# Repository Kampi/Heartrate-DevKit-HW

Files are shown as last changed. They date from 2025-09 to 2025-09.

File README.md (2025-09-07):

# ZSWatch-Heartrate-DevKit



## 📑 Table of Contents

- [ZSWatch-Heartrate-DevKit](#zswatch-heartrate-devkit)
  - [📑 Table of Contents](#-table-of-contents)
  - [📖 About](#-about)
  - [📂 Directory Breakdown](#-directory-breakdown)
  - [Purchasing](#purchasing)
  - [Ressources](#ressources)
  - [👨‍💻 Maintainer](#-maintainer)

## 📖 About

The **ZSWatch-Heartrate-DevKit** project provides the hardware design and production files for a heartrate development board tailored to the ZSWatch ecosystem.
It is built with **KiCad** and integrates a full **CI/CD pipeline** using **KiBot**, ensuring reproducible outputs for documentation, manufacturing, and releases.

Key features:

- 🛠️ Open-source hardware design
- 📦 Automated generation of Gerber, BoM, and documentation via KiBot
- 🔄 Workflow stages (DRAFT → PRELIMINARY → CHECKED → RELEASED) for structured releases
- 📝 Clear documentation and changelog to track progress
- 🌍 Designed with collaboration and transparency in mind

Please check the [wiki](https://github.com/ZSWatch/ZSWatch/wiki) for more information about the project.

## 📂 Directory Breakdown

- **`.github`**: GitHub related files
- **`.gitignore`**: Ignored files list
- **`devkit`**: KiCad project for the devkit
- **`production`**: Manufacturing outputs (Gerbers, documentation, etc.)
- **`CHANGELOG.md`**: Version history
- **`LICENSE`**: Project license (GPL-3.0)
- **`README.md`**: Project overview

## Purchasing

TBD

## Ressources

- [KiBot Template](https://github.com/nguyen-v/KDT_Hierarchical_KiBot)

## 👨‍💻 Maintainer

- [Daniel Kampert](mailto:danielkameprt@kampis-elektroecke.de)

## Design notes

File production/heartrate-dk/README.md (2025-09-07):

<p align="center" width="100%">
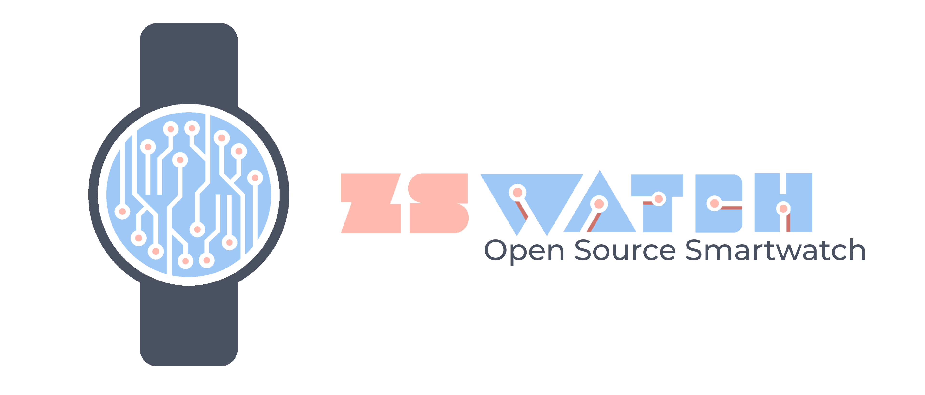
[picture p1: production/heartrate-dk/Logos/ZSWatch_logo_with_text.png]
  
</p>

<h1 align="center">Heartrate-DevKit-HW</h1>

<p align="center" width="100%">
  <a href="https://github.com/ZSWatch/Heartrate-DevKit-HW/actions/workflows/devkit.yaml">
    
  </a>
</p>

***

<p align="center">
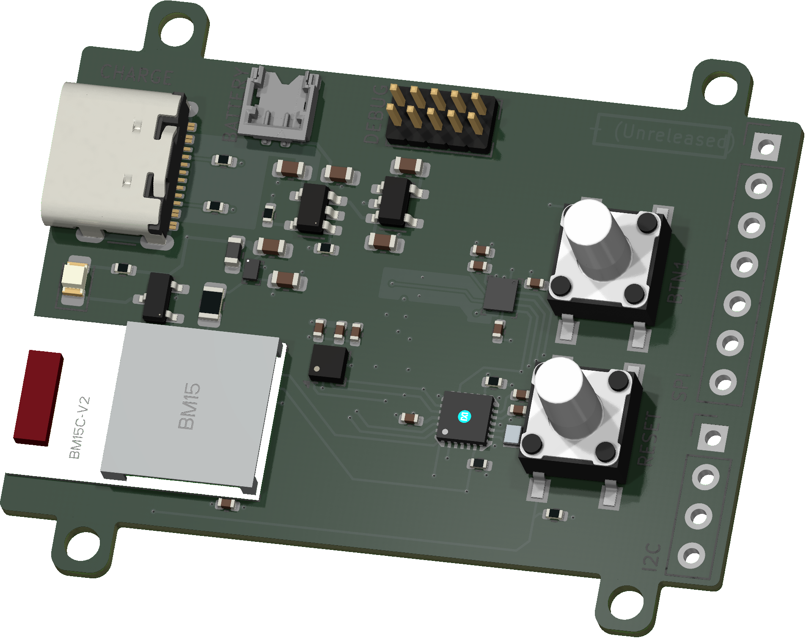
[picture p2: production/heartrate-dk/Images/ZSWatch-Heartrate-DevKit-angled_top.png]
3D Top Angled
  
&nbsp; &nbsp; &nbsp; &nbsp;
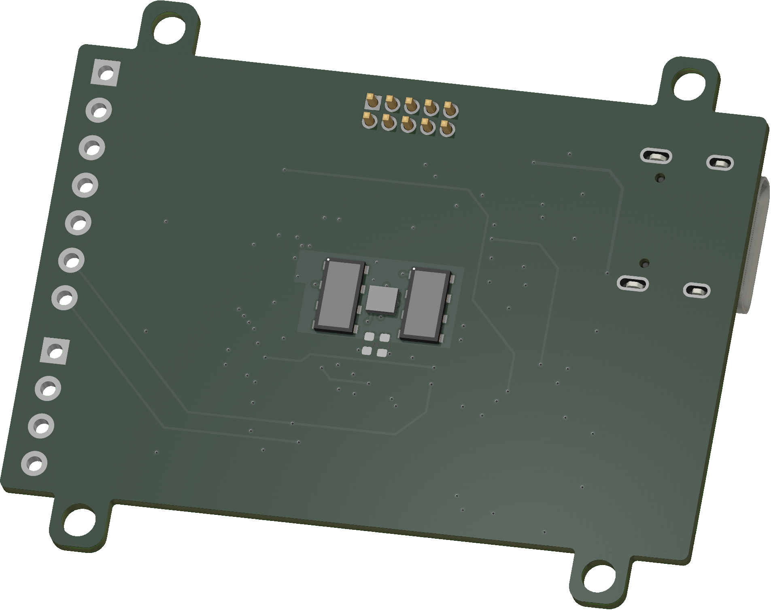
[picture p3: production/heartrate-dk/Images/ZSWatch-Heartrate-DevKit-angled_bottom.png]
3D Bottom Angled
  
</p>

***

## SPECIFICATIONS

| Parameter | Value |
| --- | --- |
| Dimensions | 45.0 × 36.9 mm |

***

## DIRECTORY STRUCTURE

    .
    ├─ Computations       # Misc calculations
    ├─ HTML               # HTML files for generated webpage
    ├─ Images             # Pictures and renders
    │
    ├─ kibot_resources    # External resources for KiBot
    │  ├─ colors          # Color theme for KiCad
    │  ├─ fonts           # Fonts used in the project
    │  ├─ scripts         # External scripts used with KiBot
    │  └─ templates       # Templates for KiBot generated reports
    │
    ├─ kibot_yaml         # KiBot YAML config files
    ├─ KiRI               # KiRI (PCB diff viewer) files
    │
    ├─ lib                # KiCad footprint and symbol libraries
    │  ├─ 3d_models       # Component 3D models
    │  ├─ lib_fp          # Footprint libraries
    │  └─ lib_sym         # Symbol libraries
    │
    ├─ Logos              # Logos
    │
    ├─ Manufacturing      # Assembly and fabrication documents
    │  ├─ Assembly        # Assembly documents (BoM, pos, notes)
    │  │
    │  └─ Fabrication     # Fabrication documents (ZIP, notes)
    │     ├─ Drill Tables # CSV drill tables
    │     └─ Gerbers      # Gerbers
    │
    ├─ Report             # Reports for ERC/DRC
    ├─ Schematic          # PDF of schematic
    ├─ Templates          # Title block templates
    ├─ Testing
    │  └─ Testpoints      # Testpoints tables
    │
    └─ Variants           # Outputs for assembly variants

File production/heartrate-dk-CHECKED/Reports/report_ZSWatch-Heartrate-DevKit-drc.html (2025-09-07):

Logo

| DRC report for ZSWatch-Heartrate-DevKit
| PCB: ZSWatch-Heartrate-DevKit Revision: + (Unreleased) Date: 2025-09-07T20:00:30+0000 KiCad Version: 9.0.1 | Errors: 1 Warnings: 15 Total: 16

Violations

Type | Description | Details
shorting_items | Items shorting two nets (nets and ) | @(219.2 mm, 138.1 mm): PCB text '+ (Unreleased)' on F.Cu @(215.1 mm, 137.2 mm): Rectangle [] on F.Cu
lib_footprint_issues | The current configuration does not include the footprint library 'Package_BGA_Kampi'. | @(195.65 mm, 149.625 mm): Footprint IC402
lib_footprint_mismatch | Footprint 'USB_C_Receptacle_GCT_USB4105-xx-A_16P_TopMnt_Horizontal' does not match copy in library 'Connector_USB'. | @(186.325 mm, 144.03 mm): Footprint X401
lib_footprint_issues | The current configuration does not include the footprint library 'Crystal_Kampi'. | @(213.5 mm, 158.275 mm): Footprint Y401
lib_footprint_issues | The current configuration does not include the footprint library 'Analog Devices'. | @(210.43 mm, 157.6 mm): Footprint IC404
lib_footprint_mismatch | Footprint 'SOT-23' does not match copy in library 'Package_TO_SOT_SMD'. | @(190.2625 mm, 152.125 mm): Footprint Q401
lib_footprint_issues | The current configuration does not include the footprint library 'Wuerth'. | @(217.85 mm, 157.525 mm): Footprint SW401
lib_footprint_mismatch | Footprint 'SOT-23-5' does not match copy in library 'Package_TO_SOT_SMD'. | @(203.7625 mm, 144.45 mm): Footprint IC401
lib_footprint_issues | The current configuration does not include the footprint library 'Fanstel'. | @(189.7 mm, 159.075 mm): Footprint M401
lib_footprint_issues | The current configuration does not include the footprint library 'Wuerth'. | @(217.85 mm, 147.3 mm): Footprint SW402
lib_footprint_mismatch | Footprint 'SOT-23-5' does not match copy in library 'Package_TO_SOT_SMD'. | @(198.8375 mm, 145.45 mm): Footprint IC403
lib_footprint_issues | The current configuration does not include the footprint library 'Molex'. | @(195.6 mm, 139.15 mm): Footprint X402
lib_footprint_issues | The current configuration does not include the footprint library 'Package_BGA_Kampi'. | @(211.2 mm, 149.475 mm): Footprint IC405
lib_footprint_issues | The current configuration does not include the footprint library 'Vishay'. | @(202.4 mm, 151.375 mm): Footprint D403
lib_footprint_issues | The current configuration does not include the footprint library 'Osram'. | @(205.2 mm, 151.375 mm): Footprint LED401
lib_footprint_issues | The current configuration does not include the footprint library 'Vishay'. | @(208.0 mm, 151.375 mm): Footprint D402

Generated by KiBot (https://github.com/INTI-CMNB/KiBot/) v1.8.4

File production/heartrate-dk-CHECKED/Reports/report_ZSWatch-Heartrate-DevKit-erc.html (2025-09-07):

Logo

| ERC report for ZSWatch-Heartrate-DevKit
| Schematic: ZSWatch-Heartrate-DevKit Revision: + (Unreleased) Date: 2025-09-07T20:00:28+0000 KiCad Version: 9.0.1 | Errors: 0 Warnings: 25 Total: 25

Sheet / (ZSWatch-Heartrate-DevKit.kicad_sch)

Type | Description | Details
footprint_link_issues | The current configuration does not include the footprint library 'Package_BGA_Kampi'. | @(0.508 mm, 0.9398 mm): Symbol IC402 [TPS61240-BGA]
lib_symbol_issues | The current configuration does not include the symbol library 'Texas Instruments' | @(0.508 mm, 0.9398 mm): Symbol IC402 [TPS61240-BGA]
lib_symbol_issues | The current configuration does not include the symbol library 'Microchip_Kampi' | @(0.4826 mm, 1.3081 mm): Symbol IC401 [MIC5365]
footprint_link_issues | The current configuration does not include the footprint library 'Molex'. | @(1.397 mm, 0.2159 mm): Symbol X402 [Conn_01x02]
footprint_link_issues | The current configuration does not include the footprint library 'Crystal_Kampi'. | @(1.9177 mm, 0.9017 mm): Symbol Y401 [Crystal]
footprint_link_issues | The current configuration does not include the footprint library 'Wuerth'. | @(0.2921 mm, 2.1082 mm): Symbol SW401 [SW_DPST]
footprint_link_issues | The current configuration does not include the footprint library 'Analog Devices'. | @(2.1463 mm, 0.8128 mm): Symbol IC404 [MAX32664-SPI-TQFN]
lib_symbol_issues | The current configuration does not include the symbol library 'Analog Devices' | @(2.1463 mm, 0.8128 mm): Symbol IC404 [MAX32664-SPI-TQFN]
footprint_link_issues | The current configuration does not include the footprint library 'Fanstel'. | @(0.8128 mm, 2.3495 mm): Symbol M401 [BM15C]
lib_symbol_issues | The current configuration does not include the symbol library 'Fanstel' | @(0.8128 mm, 2.3495 mm): Symbol M401 [BM15C]
footprint_link_issues | The current configuration does not include the footprint library 'Wuerth'. | @(1.3335 mm, 2.5019 mm): Symbol SW402 [SW_DPST]
footprint_link_issues | The current configuration does not include the footprint library 'Package_BGA_Kampi'. | @(3.1496 mm, 0.6731 mm): Symbol IC405 [MAX86141]
lib_symbol_issues | The current configuration does not include the symbol library 'Analog Devices' | @(3.1496 mm, 0.6731 mm): Symbol IC405 [MAX86141]
footprint_link_issues | The current configuration does not include the footprint library 'Vishay'. | @(3.4163 mm, 0.7366 mm): Symbol D402 [D_Photo]
footprint_link_issues | The current configuration does not include the footprint library 'Vishay'. | @(3.4163 mm, 0.7747 mm): Symbol D403 [D_Photo]
footprint_link_issues | The current configuration does not include the footprint library 'Osram'. | @(3.6957 mm, 0.6858 mm): Symbol LED401 [SFH7016]
lib_symbol_issues | The current configuration does not include the symbol library 'Osram' | @(3.6957 mm, 0.6858 mm): Symbol LED401 [SFH7016]
lib_symbol_issues | The current configuration does not include the symbol library 'ST' | @(3.2004 mm, 2.0828 mm): Symbol IC406 [LIS2DS12]
unresolved_variable | Unresolved text variable | @(0.8636 mm, 0.3175 mm): Text Box
unresolved_variable | Unresolved text variable | @(0.889 mm, 0.3556 mm): Text Box
unresolved_variable | Unresolved text variable | @(1.524 mm, 0.3175 mm): Text Box
unresolved_variable | Unresolved text variable | @(1.5494 mm, 0.3556 mm): Text Box
unresolved_variable | Unresolved text variable | @(2.1844 mm, 0.3175 mm): Text Box
unresolved_variable | Unresolved text variable | @(2.2098 mm, 0.3556 mm): Text Box

Sheet /Project Architecture/Main/ (Main.kicad_sch)

Type | Description | Details
multiple_net_names | Both +1V8 and VDD are attached to the same items; +1V8 will be used in the netlist | @(1.9177 mm, 2.4384 mm): Symbol #PWR0426 Pin 1 [Power input, Line] @(0.8128 mm, 1.9431 mm): Symbol M401 Hidden pin C8 [VDD, Power input, Line]

Generated by KiBot (https://github.com/INTI-CMNB/KiBot/) v1.8.4

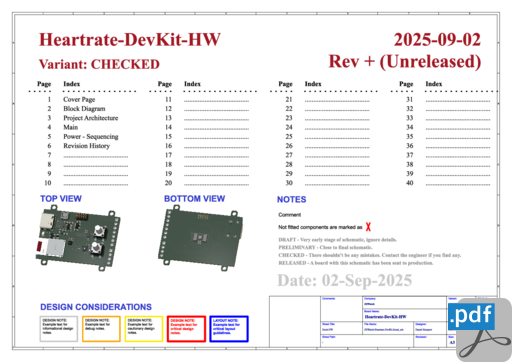
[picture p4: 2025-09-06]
production/heartrate-dk/HTML/images/cat_pdf_schematic_ZSWatch-Heartrate-DevKit-schematic.png

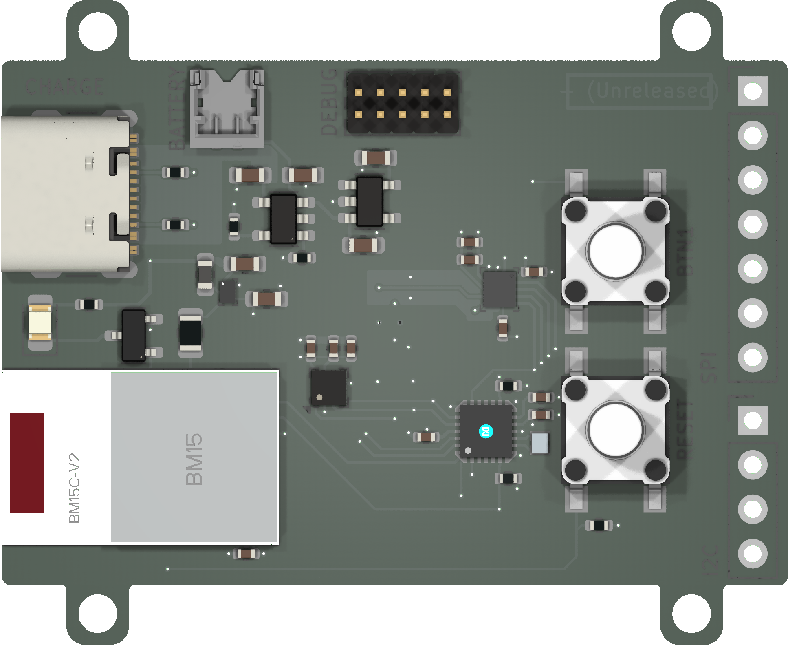
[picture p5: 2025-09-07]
production/heartrate-dk-CHECKED/Images/ZSWatch-Heartrate-DevKit-top.png

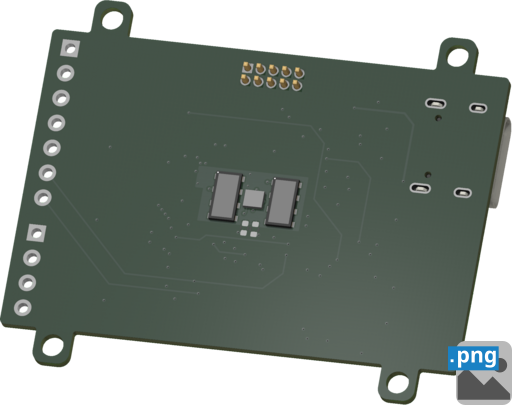
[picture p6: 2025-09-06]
production/heartrate-dk/HTML/images/cat_png_3d_viewer_angled_bottom_ZSWatch-Heartrate-DevKit-angled_bottom.png

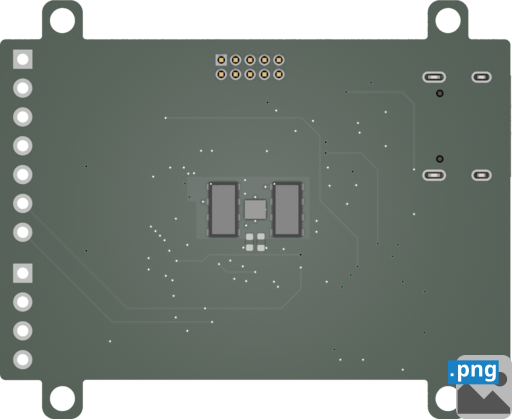
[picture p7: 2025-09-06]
production/heartrate-dk/HTML/images/cat_png_3d_viewer_bottom_ZSWatch-Heartrate-DevKit-bottom.png

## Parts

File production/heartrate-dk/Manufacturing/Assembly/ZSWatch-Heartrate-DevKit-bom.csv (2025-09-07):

Row | Quantity Per PCB | References | Value | Datasheet | Footprint | Description | manf | manf# | mouser#
1 | 4 | C406 C414 C415 C416 | 100n | https://www.yageogroup.com/content/datasheet/asset/file/KEM_C1002_X7R_SMD | C_0402_1005Metric | Unpolarized capacitor, small symbol | KEMET | C0402C104K4RAC7411 | 80-C0402C104K4R7411
2 | 2 | C402 C404 | 1u | https://www.mouser.de/datasheet/2/40/cx5r-2835979.pdf | C_0603_1608Metric | Unpolarized capacitor, small symbol | KYOCERA AVX | 06035C105MAT2A | 581-06035C105MAT2A
3 | 4 | C408 C409 C410 C413 | 1u | https://www.mouser.de/datasheet/2/40/cx5r-2835979.pdf | C_0402_1005Metric | Unpolarized capacitor, small symbol | KYOCERA AVX | 04023D105KAT2A | 581-04023D105KAT2A
4 | 1 | C401 | 2u2 | https://www.mouser.de/datasheet/2/40/cx5r-2835979.pdf | C_0603_1608Metric | Unpolarized capacitor, small symbol | KYOCERA AVX | 06033D225MAT2A | 581-06033D225MAT2A
5 | 3 | C403 C405 C407 | 4u7 | https://www.mouser.de/datasheet/2/396/mlcc02_e-1307760.pdf | C_0603_1608Metric | Unpolarized capacitor, small symbol | TAIYO YUDEN | LMK107BJ475KA-T | 963-LMK107BJ475KA-T
6 | 2 | C411 C412 | 10u | https://www.mouser.de/datasheet/2/396/mlcc02_e-1307760.pdf | C_0402_1005Metric | Unpolarized capacitor, small symbol | TAIYO YUDEN | AMK105CBJ106MV-F | 963-AMK105CBJ106MV-F
7 | 1 | C417 | 22u | https://www.mouser.de/datasheet/2/396/Taiyo_Yuden_2_8_2024_MEASJ063BB5225MF1A01_SS__1_-3395906.pdf | C_0402_1005Metric | Unpolarized capacitor, small symbol | TAIYO YUDEN | MEASP105CC6226MF1A01 | 963-MEASP105CC62261A
8 | 1 | D401 | STATUS | https://www.mouser.de/datasheet/2/678/hsmq_c170_t0000_ds100-2498198.pdf | LED_0805_2012Metric_Pad1.15x1.40mm_HandSolder | Light emitting diode | Broadcom / Avago | HSMQ-C170-T0000 | 630-HSMQ-C170-T0000
9 | 2 | D402 D403 | VEMD8082 | https://www.vishay.com/docs/80381/vemd8082.pdf | VEMD808x | Photodiode | Vishay Semiconductors | VEMD8082 | 78-VEMD8082
10 | 1 | IC406 | LIS2DS12 | https://www.st.com/resource/en/datasheet/lis2ds12.pdf | LGA-12_2x2mm_P0.5mm |  | STMicroelectronics | LIS2DS12 | 511-LIS2DS12
11 | 1 | IC404 | MAX32664 | https://www.analog.com/media/en/technical-documentation/data-sheets/MAX32664.pdf | MAX32664GTG |  | Analog Devices / Maxim Integrated | MAX32664GTGC+ | 700-MAX32664GTGC+
12 | 1 | IC405 | MAX86141 | https://www.analog.com/media/en/technical-documentation/data-sheets/max86140-max86141.pdf | THIN-WLP-20_2.228x1.967mm_P0.4mm |  | Analog Devices / Maxim Integrated | MAX86141ENP+T | 700-MAX86141ENP+T
13 | 1 | IC403 | MCP73832-2-OT | http://ww1.microchip.com/downloads/en/DeviceDoc/20001984g.pdf | SOT-23-5 | Single cell, Li-Ion/Li-Po charge management controller, 4.20V, Open-Drain Status Output, in SOT23-5 package | Microchip Technology / Atmel | MCP73832T-2ACI/OT | 579-MCP73832T-2ACI/OT
14 | 1 | IC401 | MIC5365-1.8 | https://ww1.microchip.com/downloads/en/DeviceDoc/mic5365.pdf | SOT-23-5 |  | Microchip Technology | MIC5365-1.8YD5-TR | 998- MIC5365-1.8YD5-TR
15 | 1 | IC402 | TPS61240 | https://www.ti.com/lit/ds/symlink/tps61240.pdf?ts=1729943439201 | DSBGA-6_0.886x1.288mm_2x3_P0.4mm |  | Texas Instruments | TPS61240YFFR | 595-TPS61240YFFR
16 | 1 | L401 | 1u | https://www.mouser.de/datasheet/2/3/ASMCI_0603-3318216.pdf | L_0603_1608Metric | Inductor | ABRACON | ASMCI-0603-1R0M-T | 815-ASMCI-0603-1R0MT
17 | 1 | LED401 | SFH7016 | https://look.ams-osram.com/m/1a73f8d425cfcc40/original/SFH-7016.pdf | SFH7016 |  | ams OSRAM | SFH 7016 | 720-SFH7016
18 | 1 | M401 | BM15C | https://www.mouser.de/datasheet/2/915/BM15C_2bProduct_2bSpecifications-3555318.pdf | BM15C | nRF54L module with chip antenna | Fanstel | BM15C | 308-BM15C
19 | 1 | Q401 | BSS138 | https://www.onsemi.com/pub/Collateral/BSS138-D.PDF | SOT-23 | 50V Vds, 0.22A Id, N-Channel MOSFET, SOT-23 | onsemi / Fairchild | BSS138 | 512-BSS138
20 | 1 | R403 | 0R | ~ | R_0805_2012Metric | Resistor, small symbol | Vishay | CRCW08050000Z0EBC | 71-CRCW08050000Z0EBC
21 | 1 | R401 | 220R | ~ | R_0402_1005Metric | Resistor, small symbol | Bourns | CR0402-JW-221GLF | 652-CR0402-JW-221GLF
22 | 1 | R409 | 4k7 | ~ | R_0402_1005Metric | Resistor, small symbol | YAGEO | RC0402FR-7D4K7L | 603-RC0402FR-7D4K7L
23 | 2 | R404 R405 | 5k1 | ~ | R_0402_1005Metric | Resistor, small symbol | Bourns | CR0402-FX-5101GLF | 652-CR0402-FX-5101GLF
24 | 4 | R402 R406 R407 R408 | 10k | ~ | R_0402_1005Metric | Resistor, small symbol | Bourns | CR0402-JW-103GLF | 652-CR0402-JW-103GLF
25 | 1 | SW402 | BTN1 | https://www.we-online.com/components/products/datasheet/430182095816.pdf | WS-TASV-6x6 | Double Pole Single Throw (DPST) Switch | Wurth Elektronik | 430182095816 | 710-430182095816
26 | 1 | SW401 | RESET | https://www.we-online.com/components/products/datasheet/430182095816.pdf | WS-TASV-6x6 | Double Pole Single Throw (DPST) Switch | Wurth Elektronik | 430182095816 | 710-430182095816
27 | 1 | X402 | BATTERY | https://www.molex.com/en-us/products/part-detail-pdf/781710002?display=pdf | 78171-0002 | Generic connector, single row, 01x02, script generated (kicad-library-utils/schlib/autogen/connector/) | Molex | 78171-0002 | 538-78171-0002
28 | 1 | X401 | CHARGE | https://www.usb.org/sites/default/files/documents/usb_type-c.zip | USB_C_Receptacle_GCT_USB4105-xx-A_16P_TopMnt_Horizontal | USB 2.0-only 14P Type-C Receptacle connector | GCT | USB4105-GF-A-120 | 640-USB4105-GF-A-120
29 | 1 | X403 | DEBUG | http://infocenter.arm.com/help/topic/com.arm.doc.ddi0314h/DDI0314H_coresight_components_trm.pdf | PinHeader_2x05_P1.27mm_Vertical | Cortex Debug Connector, standard ARM Cortex-M SWD and JTAG interface | Wurth Elektronik | 623310235521 | 710-623310235521
30 | 1 | Y401 | 32kHz | https://www.mouser.de/datasheet/2/122/ECX_1210-2400578.pdf | ECS_ECX-1210 | Two pin crystal | ECS | ECS-.327-6-1210-TR | 520-.327-6-1210-TR

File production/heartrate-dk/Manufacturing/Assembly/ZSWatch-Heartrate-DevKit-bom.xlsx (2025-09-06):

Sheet: BoM
Bill of Materials
Schematic: | ZSWatch-Heartrate-DevKit | Component Groups: | 33
Variant: | CHECKED | Component Count: | 48 (45 SMD/ 3 THT)
Revision: |  | Fitted Components: | 45 (44 SMD/ 1 THT)
Date: | 2025-07-13 | Number of PCBs: | 1
KiCad Version: | 9.0.1+1 | Total Components: | 45
Row | Quantity Per PCB | References | Value | Datasheet | Footprint | Description | manf | manf#
1 | 4 | C406 C414 C415 C416 | 100n | https://www.yageogroup.com/content/datasheet/asset/file/KEM_C1002_X7R_SMD | C_0402_1005Metric | Unpolarized capacitor, small symbol | KEMET | C0402C104K4RAC7411
2 | 2 | C402 C404 | 1u | https://www.mouser.de/datasheet/2/40/cx5r-2835979.pdf | C_0603_1608Metric | Unpolarized capacitor, small symbol | KYOCERA AVX | 06035C105MAT2A
3 | 4 | C408 C409 C410 C413 | 1u | https://www.mouser.de/datasheet/2/40/cx5r-2835979.pdf | C_0402_1005Metric | Unpolarized capacitor, small symbol | KYOCERA AVX | 04023D105KAT2A
4 | 1 | C401 | 2u2 | https://www.mouser.de/datasheet/2/40/cx5r-2835979.pdf | C_0603_1608Metric | Unpolarized capacitor, small symbol | KYOCERA AVX | 06033D225MAT2A
5 | 3 | C403 C405 C407 | 4u7 | https://www.mouser.de/datasheet/2/396/mlcc02_e-1307760.pdf | C_0603_1608Metric | Unpolarized capacitor, small symbol | TAIYO YUDEN | LMK107BJ475KA-T
6 | 2 | C411 C412 | 10u | https://www.mouser.de/datasheet/2/396/mlcc02_e-1307760.pdf | C_0402_1005Metric | Unpolarized capacitor, small symbol | TAIYO YUDEN | AMK105CBJ106MV-F
7 | 1 | C417 | 22u | https://www.mouser.de/datasheet/2/396/Taiyo_Yuden_2_8_2024_MEASJ063BB5225MF1A01_SS__1_-3395906.pdf | C_0402_1005Metric | Unpolarized capacitor, small symbol | TAIYO YUDEN | MEASP105CC6226MF1A01
8 | 1 | D401 | STATUS | https://www.mouser.de/datasheet/2/678/hsmq_c170_t0000_ds100-2498198.pdf | LED_0805_2012Metric_Pad1.15x1.40mm_HandSolder | Light emitting diode | Broadcom / Avago | HSMQ-C170-T0000
9 | 2 | D402 D403 | VEMD8082 | https://www.vishay.com/docs/80381/vemd8082.pdf | VEMD808x | Photodiode | Vishay Semiconductors | VEMD8082
10 | 1 | IC406 | LIS2DS12 | https://www.st.com/resource/en/datasheet/lis2ds12.pdf | LGA-12_2x2mm_P0.5mm |  | STMicroelectronics | LIS2DS12
11 | 1 | IC404 | MAX32664 | https://www.analog.com/media/en/technical-documentation/data-sheets/MAX32664.pdf | MAX32664GTG |  | Analog Devices / Maxim Integrated | MAX32664GTGC+
12 | 1 | IC405 | MAX86141 | https://www.analog.com/media/en/technical-documentation/data-sheets/max86140-max86141.pdf | THIN-WLP-20_2.228x1.967mm_P0.4mm |  | Analog Devices / Maxim Integrated | MAX86141ENP+T
13 | 1 | IC403 | MCP73832-2-OT | http://ww1.microchip.com/downloads/en/DeviceDoc/20001984g.pdf | SOT-23-5 | Single cell, Li-Ion/Li-Po charge management controller, 4.20V, Open-Drain Status Output, in SOT23-5 package | Microchip Technology / Atmel | MCP73832T-2ACI/OT
14 | 1 | IC401 | MIC5365-1.8 | https://ww1.microchip.com/downloads/en/DeviceDoc/mic5365.pdf | SOT-23-5 |  | Microchip Technology | MIC5365-1.8YD5-TR
15 | 1 | IC402 | TPS61240 | https://www.ti.com/lit/ds/symlink/tps61240.pdf?ts=1729943439201 | DSBGA-6_0.886x1.288mm_2x3_P0.4mm |  | Texas Instruments | TPS61240YFFR
16 | 1 | L401 | 1u | https://www.mouser.de/datasheet/2/3/ASMCI_0603-3318216.pdf | L_0603_1608Metric | Inductor | ABRACON | ASMCI-0603-1R0M-T
17 | 1 | LED401 | SFH7016 | https://look.ams-osram.com/m/1a73f8d425cfcc40/original/SFH-7016.pdf | SFH7016 |  | ams OSRAM | SFH 7016
18 | 1 | M401 | BM15C | https://www.mouser.de/datasheet/2/915/BM15C_2bProduct_2bSpecifications-3555318.pdf | BM15C | nRF54L module with chip antenna | Fanstel | BM15C
19 | 1 | Q401 | BSS138 | https://www.onsemi.com/pub/Collateral/BSS138-D.PDF | SOT-23 | 50V Vds, 0.22A Id, N-Channel MOSFET, SOT-23 | onsemi / Fairchild | BSS138
20 | 1 | R403 | 0R | ~ | R_0805_2012Metric | Resistor, small symbol | Vishay | CRCW08050000Z0EBC
21 | 1 | R401 | 220R | ~ | R_0402_1005Metric | Resistor, small symbol | Bourns | CR0402-JW-221GLF
22 | 1 | R409 | 4k7 | ~ | R_0402_1005Metric | Resistor, small symbol | YAGEO | RC0402FR-7D4K7L
23 | 2 | R404 R405 | 5k1 | ~ | R_0402_1005Metric | Resistor, small symbol | Bourns | CR0402-FX-5101GLF
24 | 4 | R402 R406 R407 R408 | 10k | ~ | R_0402_1005Metric | Resistor, small symbol | Bourns | CR0402-JW-103GLF
25 | 1 | SW402 | BTN1 | https://www.we-online.com/components/products/datasheet/430182095816.pdf | WS-TASV-6x6 | Double Pole Single Throw (DPST) Switch | Wurth Elektronik | 430182095816
26 | 1 | SW401 | RESET | https://www.we-online.com/components/products/datasheet/430182095816.pdf | WS-TASV-6x6 | Double Pole Single Throw (DPST) Switch | Wurth Elektronik | 430182095816
27 | 1 | X402 | BATTERY | https://www.molex.com/en-us/products/part-detail-pdf/781710002?display=pdf | 78171-0002 | Generic connector, single row, 01x02, script generated (kicad-library-utils/schlib/autogen/connector/) | Molex | 78171-0002
28 | 1 | X401 | CHARGE | https://www.usb.org/sites/default/files/documents/usb_type-c.zip | USB_C_Receptacle_GCT_USB4105-xx-A_16P_TopMnt_Horizontal | USB 2.0-only 14P Type-C Receptacle connector | GCT | USB4105-GF-A-120
29 | 1 | X403 | DEBUG | http://infocenter.arm.com/help/topic/com.arm.doc.ddi0314h/DDI0314H_coresight_components_trm.pdf | PinHeader_2x05_P1.27mm_Vertical | Cortex Debug Connector, standard ARM Cortex-M SWD and JTAG interface | Wurth Elektronik | 623310235521
30 | 1 | Y401 | 32kHz | https://www.mouser.de/datasheet/2/122/ECX_1210-2400578.pdf | ECS_ECX-1210 | Two pin crystal | ECS | ECS-.327-6-1210-TR

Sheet: DNF
Bill of Materials
Schematic: | ZSWatch-Heartrate-DevKit | Component Groups: | 33
Variant: | CHECKED | Component Count: | 48 (45 SMD/ 3 THT)
Revision: |  | Fitted Components: | 45 (44 SMD/ 1 THT)
Date: | 2025-07-13 | Number of PCBs: | 1
KiCad Version: | 9.0.1+1 | Total Components: | 45
Row | Quantity Per PCB | References | Value | Datasheet | Footprint | Description | manf | manf#
1 | 1 | J401 | I2C | ~ | PinHeader_1x04_P2.54mm_Vertical | Generic connector, single row, 01x04, script generated (kicad-library-utils/schlib/autogen/connector/)
2 | 1 | J402 | SPI | ~ | PinHeader_1x07_P2.54mm_Vertical | Generic connector, single row, 01x07, script generated (kicad-library-utils/schlib/autogen/connector/)
3 | 1 | R410 | ~ | ~ | R_0402_1005Metric | Resistor, small symbol

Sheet: Costs
Bill of Materials
Schematic: | ZSWatch-Heartrate-DevKit |  |  |  |  | Board Qty: | 1
Variant: | CHECKED |  |  |  |  | Unit Cost: | $0.00
Revision: |  |  |  |  |  | Total Cost: | $0.00 |  |  |  |  | $0.00 | 0 of 30 parts found
Date: | 2025-07-13
KiCad Version: | 9.0.1+1
Global Part Info |  |  |  |  |  |  |  | Mouser
References | Value | Footprint | Manf | Manf# | Build Quantity | Unit$ | Ext$ | Avail | Purch | Unit$ | MOQ | Ext$ | Cat#
C406 C414 C415 C416 | 100n | C_0402_1005Metric | KEMET | C0402C104K4RAC7411 (https://www.yageogroup.com/content/datasheet/asset/file/KEM_C1002_X7R_SMD) | 4
C402 C404 | 1u | C_0603_1608Metric | KYOCERA AVX | 06035C105MAT2A (https://www.mouser.de/datasheet/2/40/cx5r-2835979.pdf) | 2
C408 C409 C410 C413 | 1u | C_0402_1005Metric | KYOCERA AVX | 04023D105KAT2A (https://www.mouser.de/datasheet/2/40/cx5r-2835979.pdf) | 4
C401 | 2u2 | C_0603_1608Metric | KYOCERA AVX | 06033D225MAT2A (https://www.mouser.de/datasheet/2/40/cx5r-2835979.pdf) | 1
C403 C405 C407 | 4u7 | C_0603_1608Metric | TAIYO YUDEN | LMK107BJ475KA-T (https://www.mouser.de/datasheet/2/396/mlcc02_e-1307760.pdf) | 3
C411 C412 | 10u | C_0402_1005Metric | TAIYO YUDEN | AMK105CBJ106MV-F (https://www.mouser.de/datasheet/2/396/mlcc02_e-1307760.pdf) | 2
C417 | 22u | C_0402_1005Metric | TAIYO YUDEN | MEASP105CC6226MF1A01 (https://www.mouser.de/datasheet/2/396/Taiyo_Yuden_2_8_2024_MEASJ063BB5225MF1A01_SS__1_-3395906.pdf) | 1
D401 | STATUS | LED_0805_2012Metric_Pad1.15x1.40mm_HandSolder | Broadcom / Avago | HSMQ-C170-T0000 (https://www.mouser.de/datasheet/2/678/hsmq_c170_t0000_ds100-2498198.pdf) | 1
D402 D403 | VEMD8082 | VEMD808x | Vishay Semiconductors | VEMD8082 (https://www.vishay.com/docs/80381/vemd8082.pdf) | 2
IC406 | LIS2DS12 | LGA-12_2x2mm_P0.5mm | STMicroelectronics | LIS2DS12 (https://www.st.com/resource/en/datasheet/lis2ds12.pdf) | 1
IC404 | MAX32664 | MAX32664GTG | Analog Devices / Maxim Integrated | MAX32664GTGC+ (https://www.analog.com/media/en/technical-documentation/data-sheets/MAX32664.pdf) | 1
IC405 | MAX86141 | THIN-WLP-20_2.228x1.967mm_P0.4mm | Analog Devices / Maxim Integrated | MAX86141ENP+T (https://www.analog.com/media/en/technical-documentation/data-sheets/max86140-max86141.pdf) | 1
IC403 | MCP73832-2-OT | SOT-23-5 | Microchip Technology / Atmel | MCP73832T-2ACI/OT (http://ww1.microchip.com/downloads/en/DeviceDoc/20001984g.pdf) | 1
IC401 | MIC5365-1.8 | SOT-23-5 | Microchip Technology | MIC5365-1.8YD5-TR (https://ww1.microchip.com/downloads/en/DeviceDoc/mic5365.pdf) | 1
IC402 | TPS61240 | DSBGA-6_0.886x1.288mm_2x3_P0.4mm | Texas Instruments | TPS61240YFFR (https://www.ti.com/lit/ds/symlink/tps61240.pdf?ts=1729943439201) | 1
L401 | 1u | L_0603_1608Metric | ABRACON | ASMCI-0603-1R0M-T (https://www.mouser.de/datasheet/2/3/ASMCI_0603-3318216.pdf) | 1
LED401 | SFH7016 | SFH7016 | ams OSRAM | SFH 7016 (https://look.ams-osram.com/m/1a73f8d425cfcc40/original/SFH-7016.pdf) | 1
M401 | BM15C | BM15C | Fanstel | BM15C (https://www.mouser.de/datasheet/2/915/BM15C_2bProduct_2bSpecifications-3555318.pdf) | 1
Q401 | BSS138 | SOT-23 | onsemi / Fairchild | BSS138 (https://www.onsemi.com/pub/Collateral/BSS138-D.PDF) | 1
R403 | 0R | R_0805_2012Metric | Vishay | CRCW08050000Z0EBC | 1
R401 | 220R | R_0402_1005Metric | Bourns | CR0402-JW-221GLF | 1
R409 | 4k7 | R_0402_1005Metric | YAGEO | RC0402FR-7D4K7L | 1
R404 R405 | 5k1 | R_0402_1005Metric | Bourns | CR0402-FX-5101GLF | 2
R402 R406 R407 R408 | 10k | R_0402_1005Metric | Bourns | CR0402-JW-103GLF | 4
SW402 | BTN1 | WS-TASV-6x6 | Wurth Elektronik | 430182095816 (https://www.we-online.com/components/products/datasheet/430182095816.pdf) | 1
SW401 | RESET | WS-TASV-6x6 | Wurth Elektronik | 430182095816 (https://www.we-online.com/components/products/datasheet/430182095816.pdf) | 1
X402 | BATTERY | 78171-0002 | Molex | 78171-0002 (https://www.molex.com/en-us/products/part-detail-pdf/781710002?display=pdf) | 1
X401 | CHARGE | USB_C_Receptacle_GCT_USB4105-xx-A_16P_TopMnt_Horizontal | GCT | USB4105-GF-A-120 (https://www.usb.org/sites/default/files/documents/usb_type-c.zip) | 1
X403 | DEBUG | PinHeader_2x05_P1.27mm_Vertical | Wurth Elektronik | 623310235521 (http://infocenter.arm.com/help/topic/com.arm.doc.ddi0314h/DDI0314H_coresight_components_trm.pdf) | 1
Y401 | 32kHz | ECS_ECX-1210 | ECS | ECS-.327-6-1210-TR (https://www.mouser.de/datasheet/2/122/ECX_1210-2400578.pdf) | 1
 |  |  |  |  |  | Total Purchase: | $0.00 | Buy here (https://mouser.com/bom/) |  |  |  | $0.00
Created: | 2025-09-06 09:58:40 |  |  |  |  | Purchase description:
KiCost® v1.1.20 + KiBot v1.8.4

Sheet: Costs (DNF)
Bill of Materials
Schematic: | ZSWatch-Heartrate-DevKit |  |  |  | Board Qty: | 1
Variant: | CHECKED |  |  |  | Unit Cost: | $0.00
Revision: |  |  |  |  | Total Cost: | $0.00 |  |  |  |  | $0.00 | 0 of 3 parts found
Date: | 2025-07-13
KiCad Version: | 9.0.1+1
Global Part Info |  |  |  |  |  |  | Mouser
References | Value | Footprint | Manf# | Build Quantity | Unit$ | Ext$ | Avail | Purch | Unit$ | MOQ | Ext$ | Cat#
J401 | I2C | PinHeader_1x04_P2.54mm_Vertical |  | 1
J402 | SPI | PinHeader_1x07_P2.54mm_Vertical |  | 1
R410 | ~ | R_0402_1005Metric |  | 1
 |  |  |  |  | Total Purchase: | $0.00 | Buy here (https://mouser.com/bom/) |  |  |  | $0.00
Created: | 2025-09-06 09:58:40 |  |  |  | Purchase description:
KiCost® v1.1.20 + KiBot v1.8.4

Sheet: Colors
Columns colors
KiCad Fields (default)
Generated Fields
User Fields
Empty Fields
Costs sheet colors
Best price
No manufacturer or distributor code
Not available
Purchase quantity is more than what is available
Minimum order quantity not respected
Total available part quantity is less than needed
Total purchased part quantity is less than needed
This part is obsolete
This part is listed but is not normally stocked

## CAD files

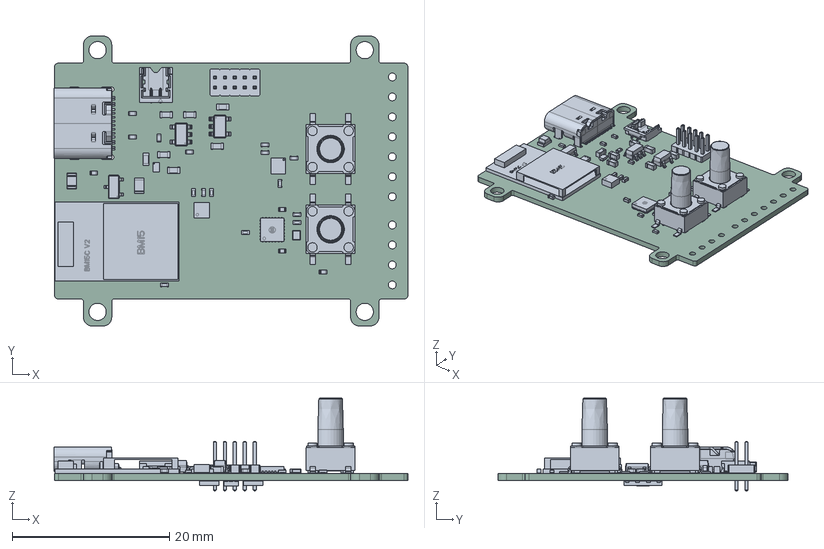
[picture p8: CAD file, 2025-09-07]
production/heartrate-dk-CHECKED/3D/ZSWatch-Heartrate-DevKit.step
45.0 x 36.9 x 11.8 mm
C_0603_1608Metric x 6
C_0402_1005Metric x 11
R_0805_2012Metric
TPS610994YFFR
USB_C_Receptacle_GCT_USB4105-xx-A_16P_TopMnt_Horizontal
R_0402_1005Metric x 8
PinHeader_2x05_P1.27mm_Vertical
LED_0805_2012Metric
solidBody
solidTop1
solidLead
MAXIM_90-100089
SOT-23
LGA-12_2x2mm_P0.5mm
SOT-23-5 x 2
BM15
BM15C-V2
L_0603_1608Metric
VEMD8080 x 2
SFH7016
kibot_rgkx_kim_PCB

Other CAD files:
production/heartrate-dk-RELEASED/3D/ZSWatch-Heartrate-DevKit.step
production/heartrate-dk/3D/ZSWatch-Heartrate-DevKit.step

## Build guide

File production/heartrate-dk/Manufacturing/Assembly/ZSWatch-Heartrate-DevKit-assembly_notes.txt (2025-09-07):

ASSEMBLY NOTES (UNLESS OTHERWISE SPECIFIED)

1)	DO NOT POPULATE PARTS ARE MARKED WITH A RED CROSS.

2)	DO NOT POPULATE PARTS ARE NOT PRESENT IN THE BOM.

3)	IF CONFLICTING INFORMATION IS FOUND BETWEEN THE ASSEMBLY
	FILE AND BOM, BOM SHOULD BE USED AS THE MAIN SOURCE.

4)	CONFORMAL COATING IS NOT REQUIRED.

5)	DOT IDENTIFIES PIN #1 LOCATION AND DEVICE ORIENTATION
	WHEN VIEWED FROM THE TOP.

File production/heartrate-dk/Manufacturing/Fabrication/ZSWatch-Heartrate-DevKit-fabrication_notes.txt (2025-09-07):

FABRICATION NOTES (UNLESS OTHERWISE SPECIFIED)

1)	FABRICATE PER IPC-6012A CLASS 2.

2)	OUTLINE DEFINED IN SEPARATE GERBER FILE WITH
	"Edge_Cuts.GBR" SUFFIX.

	DIMENSIONS OF CIRCUMSIZED RECTANGLE SHOWN ON THIS
	DRAWING FOR REFERENCE ONLY.

3)	SEE SEPARATE DRILL FILES WITH ".DRL" SUFFIX 
	FOR HOLE LOCATIONS.

	SELECTED HOLE LOCATIONS SHOWN ON THIS DRAWING 
	FOR REFERENCE ONLY.

4)	SURFACE FINISH: HAL SNPB

5)	SOLDERMASK ON BOTH SIDES OF THE BOARD SHALL 
	BE LPI, COLOR GREEN.

6)	SILK SCREEN LEGEND TO BE APPLIED PER LAYER 
	STACKUP USING BLACK NON-CONDUCTIVE EPOXY INK.

7)	ALL VIAS ARE TENTED ON BOTH SIDES UNLESS 
	SOLDERMASK OPENED IN GERBER.

8)	VENDOR SHOULD FOLLOW ROHS COMPLIANT PROCESS 
	AND Pb FREE FOR MANUFACTURING

9)	PCB MATERIAL REQUIREMENTS:

	A.	FLAMMABILITY RATING MUST MEET OR EXCEED 
		UL94V-0 REQUIREMENTS.
	B.	Tg 150 C OR EQUIVALENT.
	C.	EQUIVALENT MATERIAL SHALL BE RoHS COMPLIANT, 
		HALOGEN FREE AND APPROVED BY ZSWATCH.

10)	DESIGN GEOMETRY MINIMUM FEATURE SIZES:

	BOARD SIZE				45.000 × 36.900 mm
	BOARD THICKNESS		0.982 mm
	TRACE WIDTH			0.150 mm
	TRACE TO TRACE		0.100 mm
	MIN. HOLE (PTH)			0.150 mm
	MIN. HOLE (NPTH)		0.650 mm
	ANNULAR RING			0.100 mm
	COPPER TO HOLE		0.100 mm
	COPPER TO EDGE		0.100 mm
	HOLE TO HOLE			0.100 mm

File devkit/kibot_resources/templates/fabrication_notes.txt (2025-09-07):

FABRICATION NOTES (UNLESS OTHERWISE SPECIFIED)

1)	FABRICATE PER IPC-6012A CLASS 2.

2)	OUTLINE DEFINED IN SEPARATE GERBER FILE WITH
	"Edge_Cuts.GBR" SUFFIX.

	DIMENSIONS OF CIRCUMSIZED RECTANGLE SHOWN ON THIS
	DRAWING FOR REFERENCE ONLY.

3)	SEE SEPARATE DRILL FILES WITH ".DRL" SUFFIX 
	FOR HOLE LOCATIONS.

	SELECTED HOLE LOCATIONS SHOWN ON THIS DRAWING 
	FOR REFERENCE ONLY.

4)	SURFACE FINISH: ${pcb_finish_cap}

5)	SOLDERMASK ON BOTH SIDES OF THE BOARD SHALL 
	BE LPI, COLOR ${solder_mask_color_text_cap}.

6)	SILK SCREEN LEGEND TO BE APPLIED PER LAYER 
	STACKUP USING ${silk_screen_color_text_cap} NON-CONDUCTIVE EPOXY INK.

7)	ALL VIAS ARE TENTED ON BOTH SIDES UNLESS 
	SOLDERMASK OPENED IN GERBER.

8)	VENDOR SHOULD FOLLOW ROHS COMPLIANT PROCESS 
	AND Pb FREE FOR MANUFACTURING

9)	PCB MATERIAL REQUIREMENTS:

	A.	FLAMMABILITY RATING MUST MEET OR EXCEED 
		UL94V-0 REQUIREMENTS.
	B.	Tg 150 C OR EQUIVALENT.
	C.	EQUIVALENT MATERIAL SHALL BE RoHS COMPLIANT, 
		HALOGEN FREE AND APPROVED BY ${COMPANY_cap}.

10)	DESIGN GEOMETRY MINIMUM FEATURE SIZES:

	BOARD SIZE				${bb_w_mm} × ${bb_h_mm} mm
	BOARD THICKNESS		${thickness_mm} mm
	TRACE WIDTH			${track_mm} mm
	TRACE TO TRACE		${clearance_mm} mm
	MIN. HOLE (PTH)			${drill_pth_real_mm} mm
	MIN. HOLE (NPTH)		${drill_npth_real_mm} mm
	ANNULAR RING			${oar_mm} mm
	COPPER TO HOLE		${c2h_mm} mm
	COPPER TO EDGE		${c2e_mm} mm
	HOLE TO HOLE			${h2h_mm} mm
#?stackup and impedance_controlled

#?stackup and impedance_controlled
11)	REFER TO IMPEDANCE TABLE FOR IMPEDANCE CONTROL REQUIREMENTS.
#?stackup and impedance_controlled

#?stackup and impedance_controlled
12)	CONFIRM SPACE WIDTHS AND SPACINGS.

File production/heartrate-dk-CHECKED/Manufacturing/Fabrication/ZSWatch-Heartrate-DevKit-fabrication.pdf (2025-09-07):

# Top Fabrication (Scale 1:1)

# Heartrate-DevKit-HW Fabrication Document

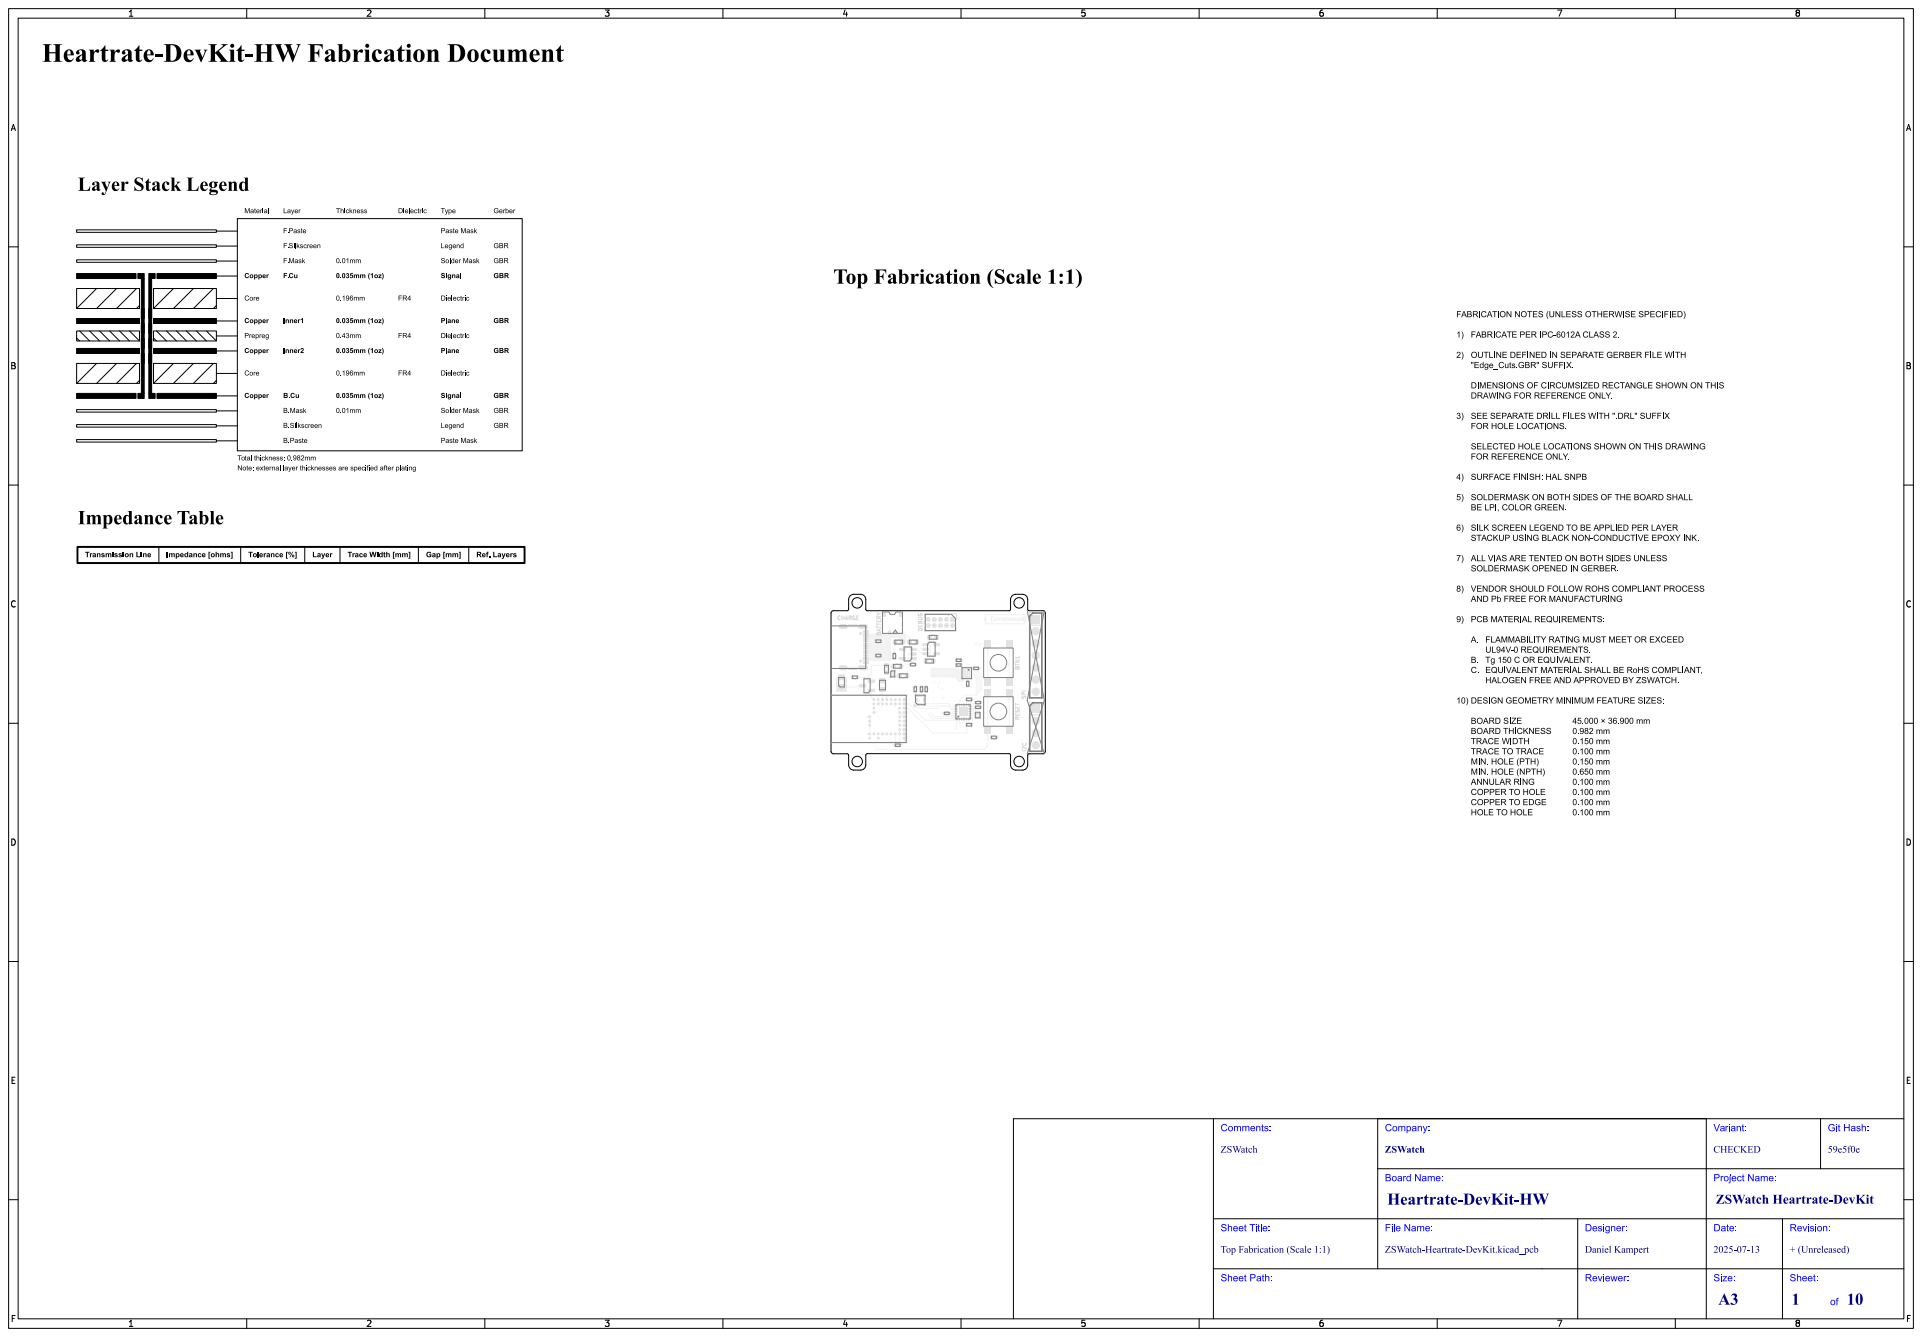
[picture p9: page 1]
Git Hash:; ZSWatch; Comments:; Sheet Path:; Sheet Title:; File Name:; Heartrate-DevKit-HW; ZSWatch Heartrate-DevKit; Company:; CHECKED; Variant:; Board Name:; Designer:; Reviewer:; Project Name:; Date:; + (Unreleased); Revision:; Size:; Sheet:; 8 BATTERY; BTN1 RESET DEBUG; I2C SPI; CHARGE

Top Fabrication (Scale 1:1)

ZSWatch-Heartrate-DevKit.kicad_pcb Daniel Kampert

# Bottom Fabrication (Scale 1:1)

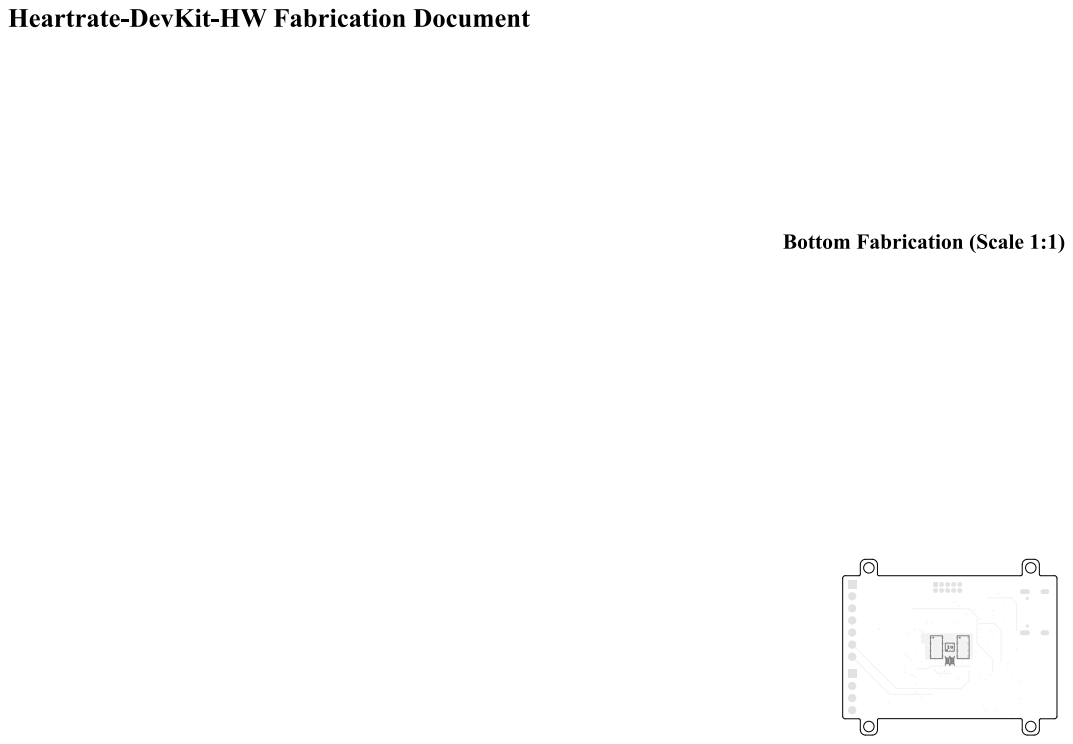
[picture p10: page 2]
Git; Hash:; ZSWatch; Comments:; Sheet Title:; File Name:; Heartrate-DevKit-HW; ZSWatch Heartrate-DevKit; Company:; CHECKED; Variant:; Board Name:; Designer:; Project Name:; Date:; + (Unreleased); Revision:

Bottom Fabrication (Scale 1:1)

ZSWatch-Heartrate-DevKit.kicad_pcb Daniel Kampert

# Drill Drawing L1 - L4 (Scale 1:1)

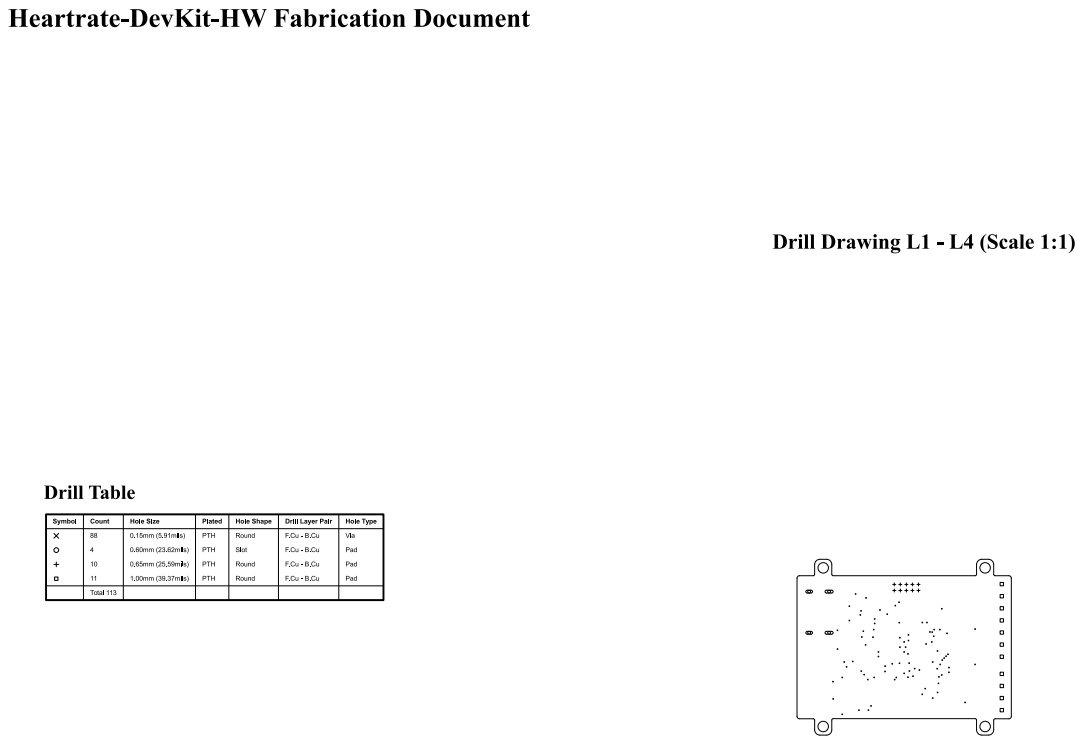
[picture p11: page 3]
Git; Hash:; ZSWatch; Comments:; Drill Drawing (L1 - L4); Sheet Title:; File Name:; Heartrate-DevKit-HW; ZSWatch Heartrate-DevKit; Company:; CHECKED; Variant:; Board Name:; Designer:; Project Name:; Date:; + (Unreleased); Revision:

ZSWatch-Heartrate-DevKit.kicad_pcb Daniel Kampert

# Drill Drawing L1 - L4 (Scale 1:1)

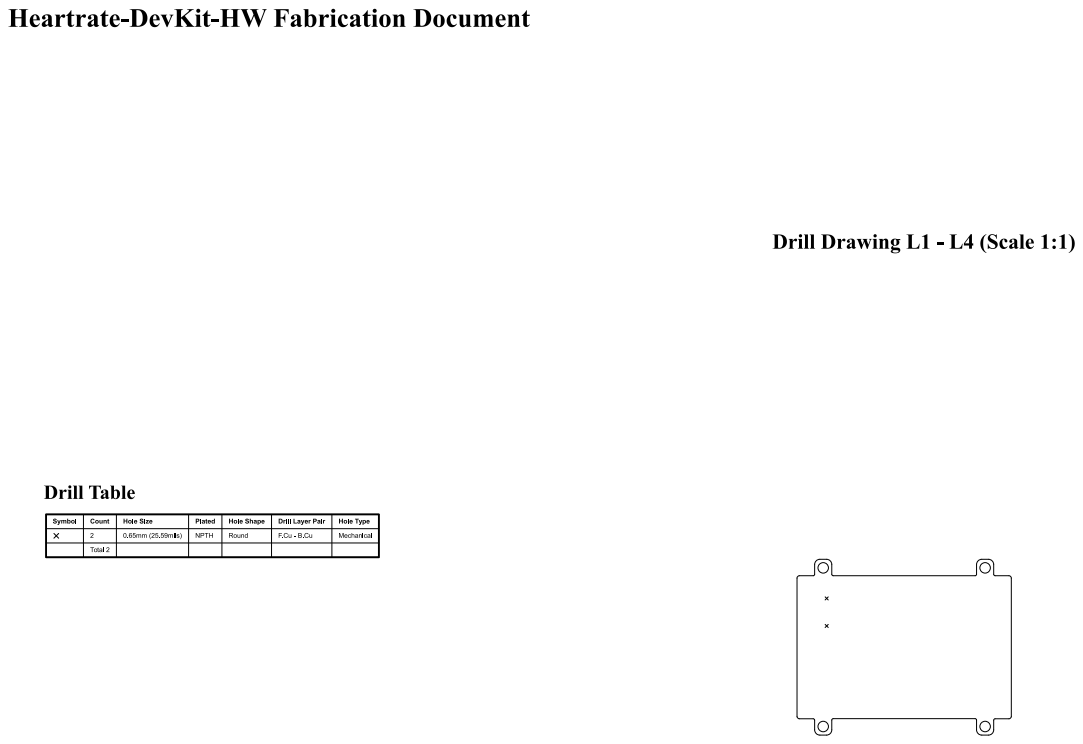
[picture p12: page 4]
Git; Hash:; ZSWatch; Comments:; Drill Drawing (L1 - L4); Sheet Title:; File Name:; Heartrate-DevKit-HW; ZSWatch Heartrate-DevKit; Company:; CHECKED; Variant:; Board Name:; Designer:; Project Name:; Date:; + (Unreleased); Revision:

ZSWatch-Heartrate-DevKit.kicad_pcb Daniel Kampert

# Top Test Points (Scale 1:1)

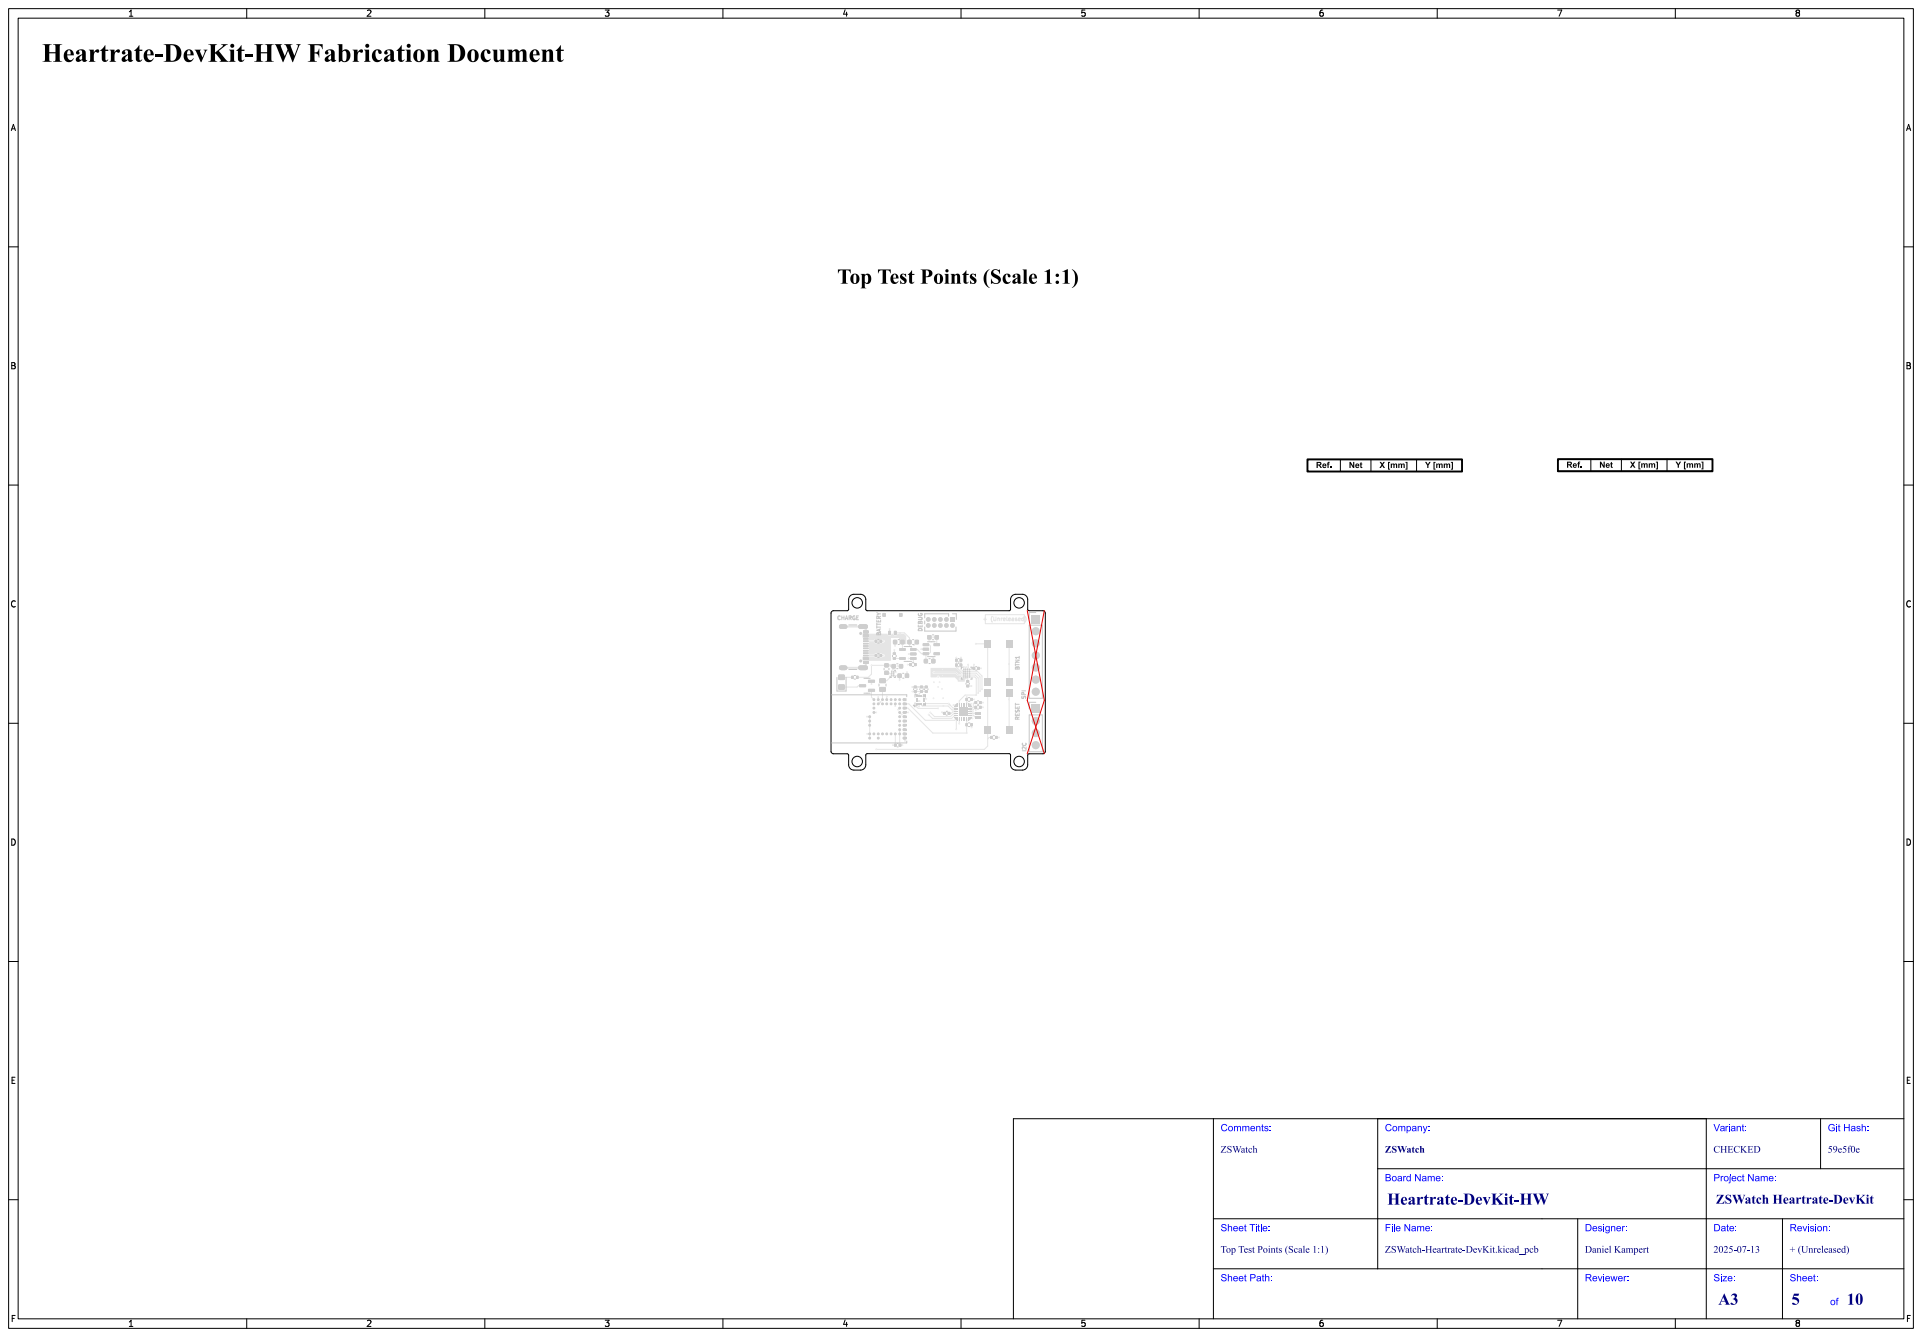
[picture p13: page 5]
Git; Hash:; ZSWatch; Comments:; Sheet Title:; File Name:; Heartrate-DevKit-HW; ZSWatch Heartrate-DevKit; Company:; CHECKED; Variant:; Board Name:; Designer:; Project Name:; Date:; + (Unreleased); Revision:; 8 BATTERY; BTN1 RESET DEBUG; I2C SPI; CHARGE

Top Test Points (Scale 1:1)

ZSWatch-Heartrate-DevKit.kicad_pcb Daniel Kampert

# Bottom Test Points (Scale 1:1)

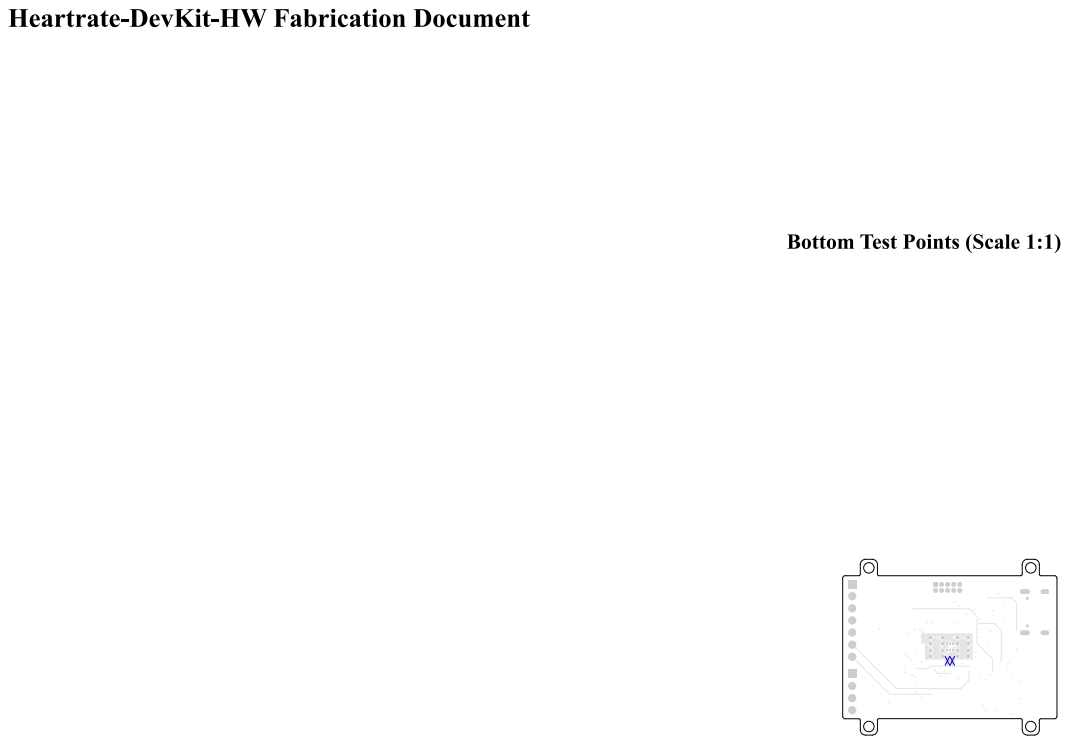
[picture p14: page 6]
Git; Hash:; ZSWatch; Comments:; Sheet Title:; File Name:; Heartrate-DevKit-HW; ZSWatch Heartrate-DevKit; Company:; CHECKED; Variant:; Board Name:; Designer:; Project Name:; Date:; + (Unreleased); Revision:

Bottom Test Points (Scale 1:1)

ZSWatch-Heartrate-DevKit.kicad_pcb Daniel Kampert

# F.Cu (Scale 1:1)

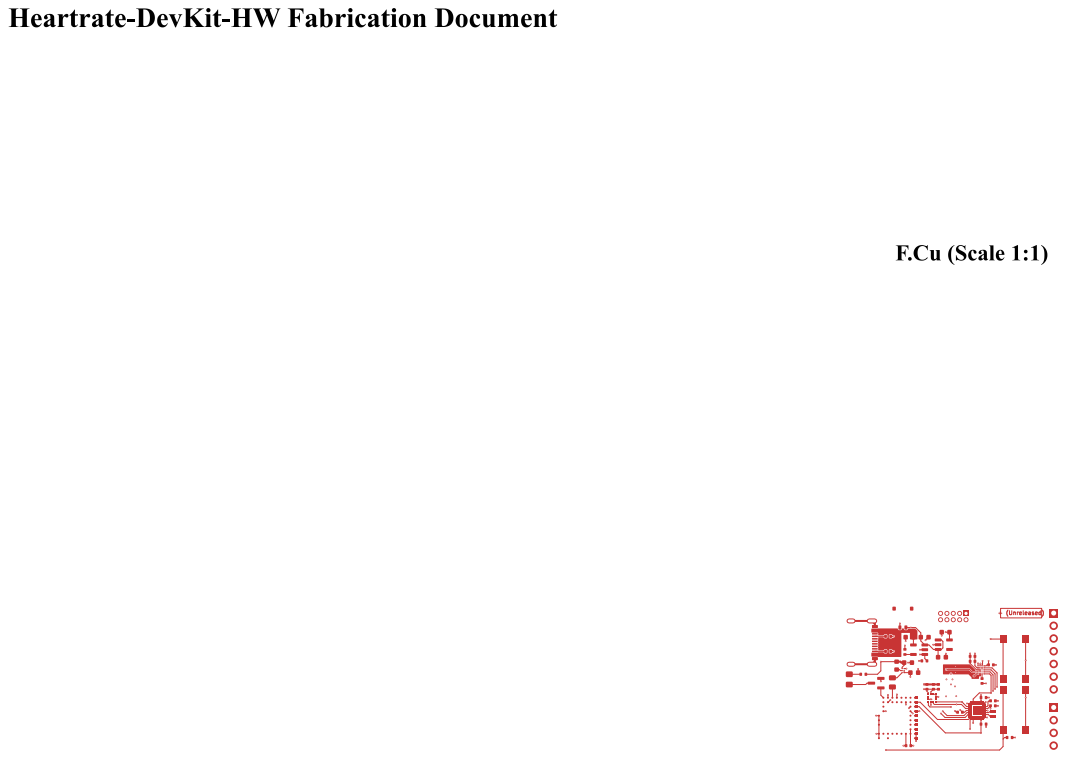
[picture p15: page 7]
Git; Hash:; ZSWatch; Comments:; F.Cu (Scale 1:1); Sheet Title:; File Name:; Heartrate-DevKit-HW; ZSWatch Heartrate-DevKit; Company:; CHECKED; Variant:; Board Name:; Designer:; Project Name:; Date:; + (Unreleased); Revision:

ZSWatch-Heartrate-DevKit.kicad_pcb Daniel Kampert

# Inner1 (Scale 1:1)

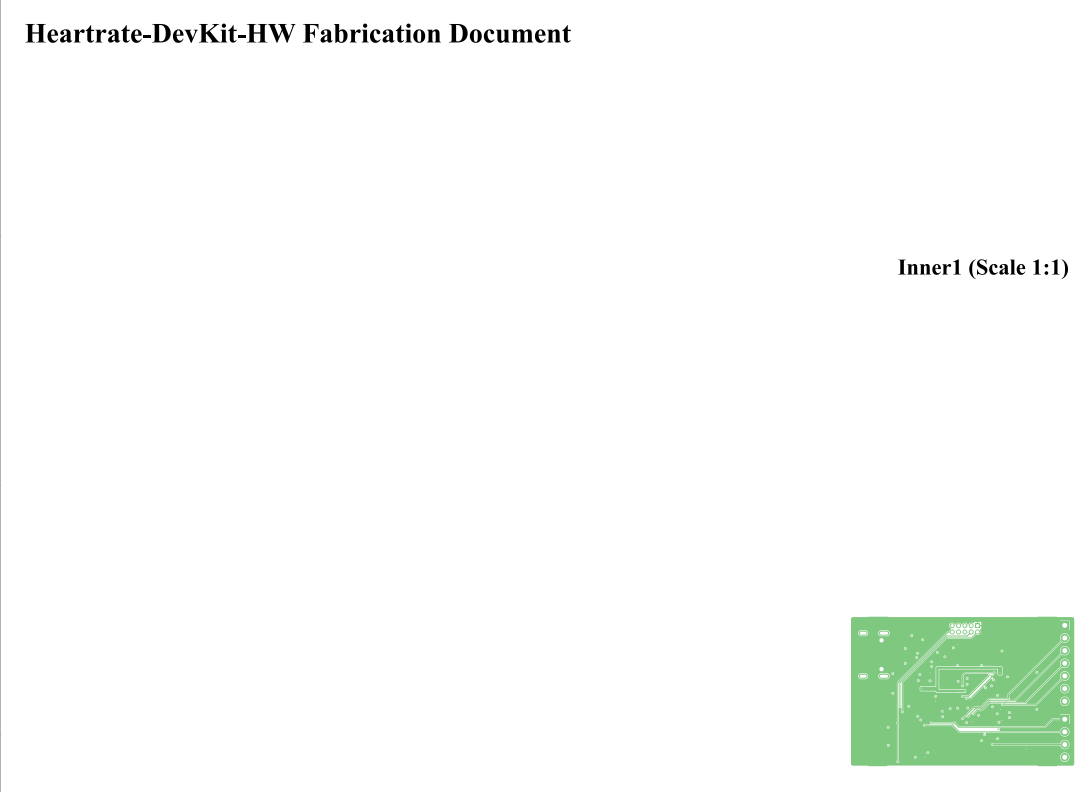
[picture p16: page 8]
Git; Hash:; ZSWatch; Comments:; Inner1 (Scale 1:1); Sheet Title:; File Name:; Heartrate-DevKit-HW; ZSWatch Heartrate-DevKit; Company:; CHECKED; Variant:; Board Name:; Designer:; Project Name:; Date:; + (Unreleased); Revision:

ZSWatch-Heartrate-DevKit.kicad_pcb Daniel Kampert

# Inner2 (Scale 1:1)

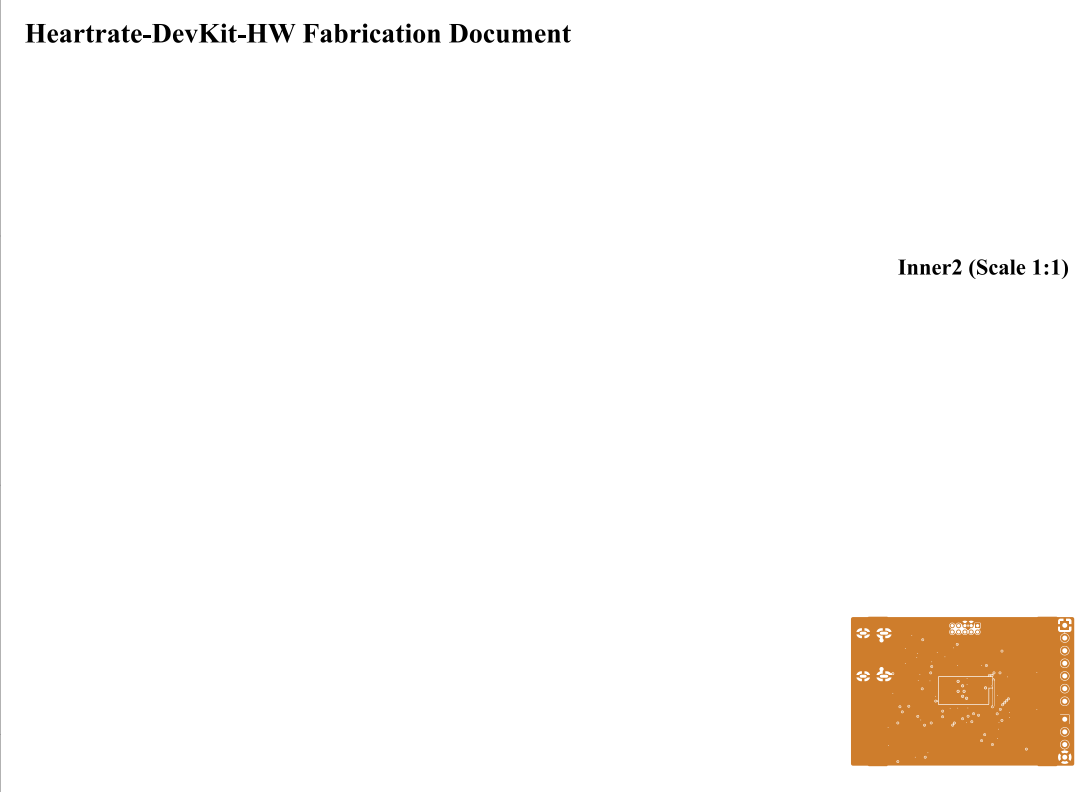
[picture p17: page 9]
Git; Hash:; ZSWatch; Comments:; Inner2 (Scale 1:1); Sheet Title:; File Name:; Heartrate-DevKit-HW; ZSWatch Heartrate-DevKit; Company:; CHECKED; Variant:; Board Name:; Designer:; Project Name:; Date:; + (Unreleased); Revision:

ZSWatch-Heartrate-DevKit.kicad_pcb Daniel Kampert

# B.Cu (Scale 1:1)

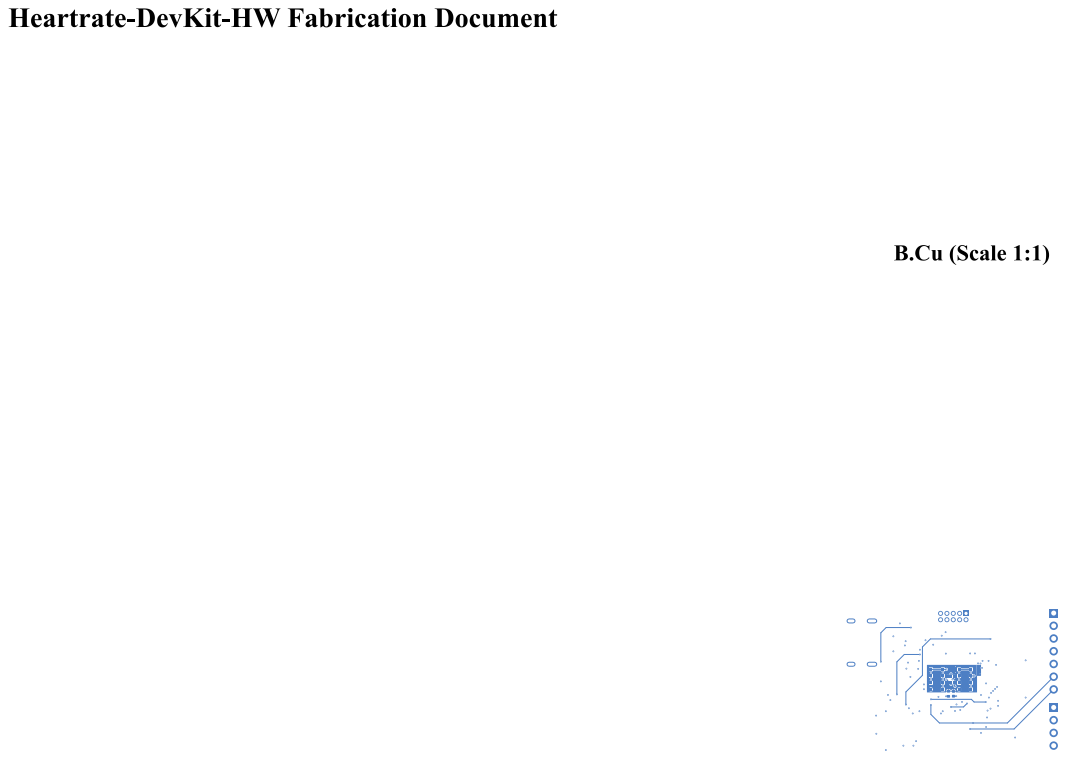
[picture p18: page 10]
Git; Hash:; ZSWatch; Comments:; B.Cu (Scale 1:1); Sheet Title:; File Name:; Heartrate-DevKit-HW; ZSWatch Heartrate-DevKit; Company:; CHECKED; Variant:; Board Name:; Designer:; Project Name:; Date:; + (Unreleased); Revision:

ZSWatch-Heartrate-DevKit.kicad_pcb Daniel Kampert

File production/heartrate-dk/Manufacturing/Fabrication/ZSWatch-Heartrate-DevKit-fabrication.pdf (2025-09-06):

# Top Fabrication (Scale 1:1)

# Heartrate-DevKit-HW Fabrication Document

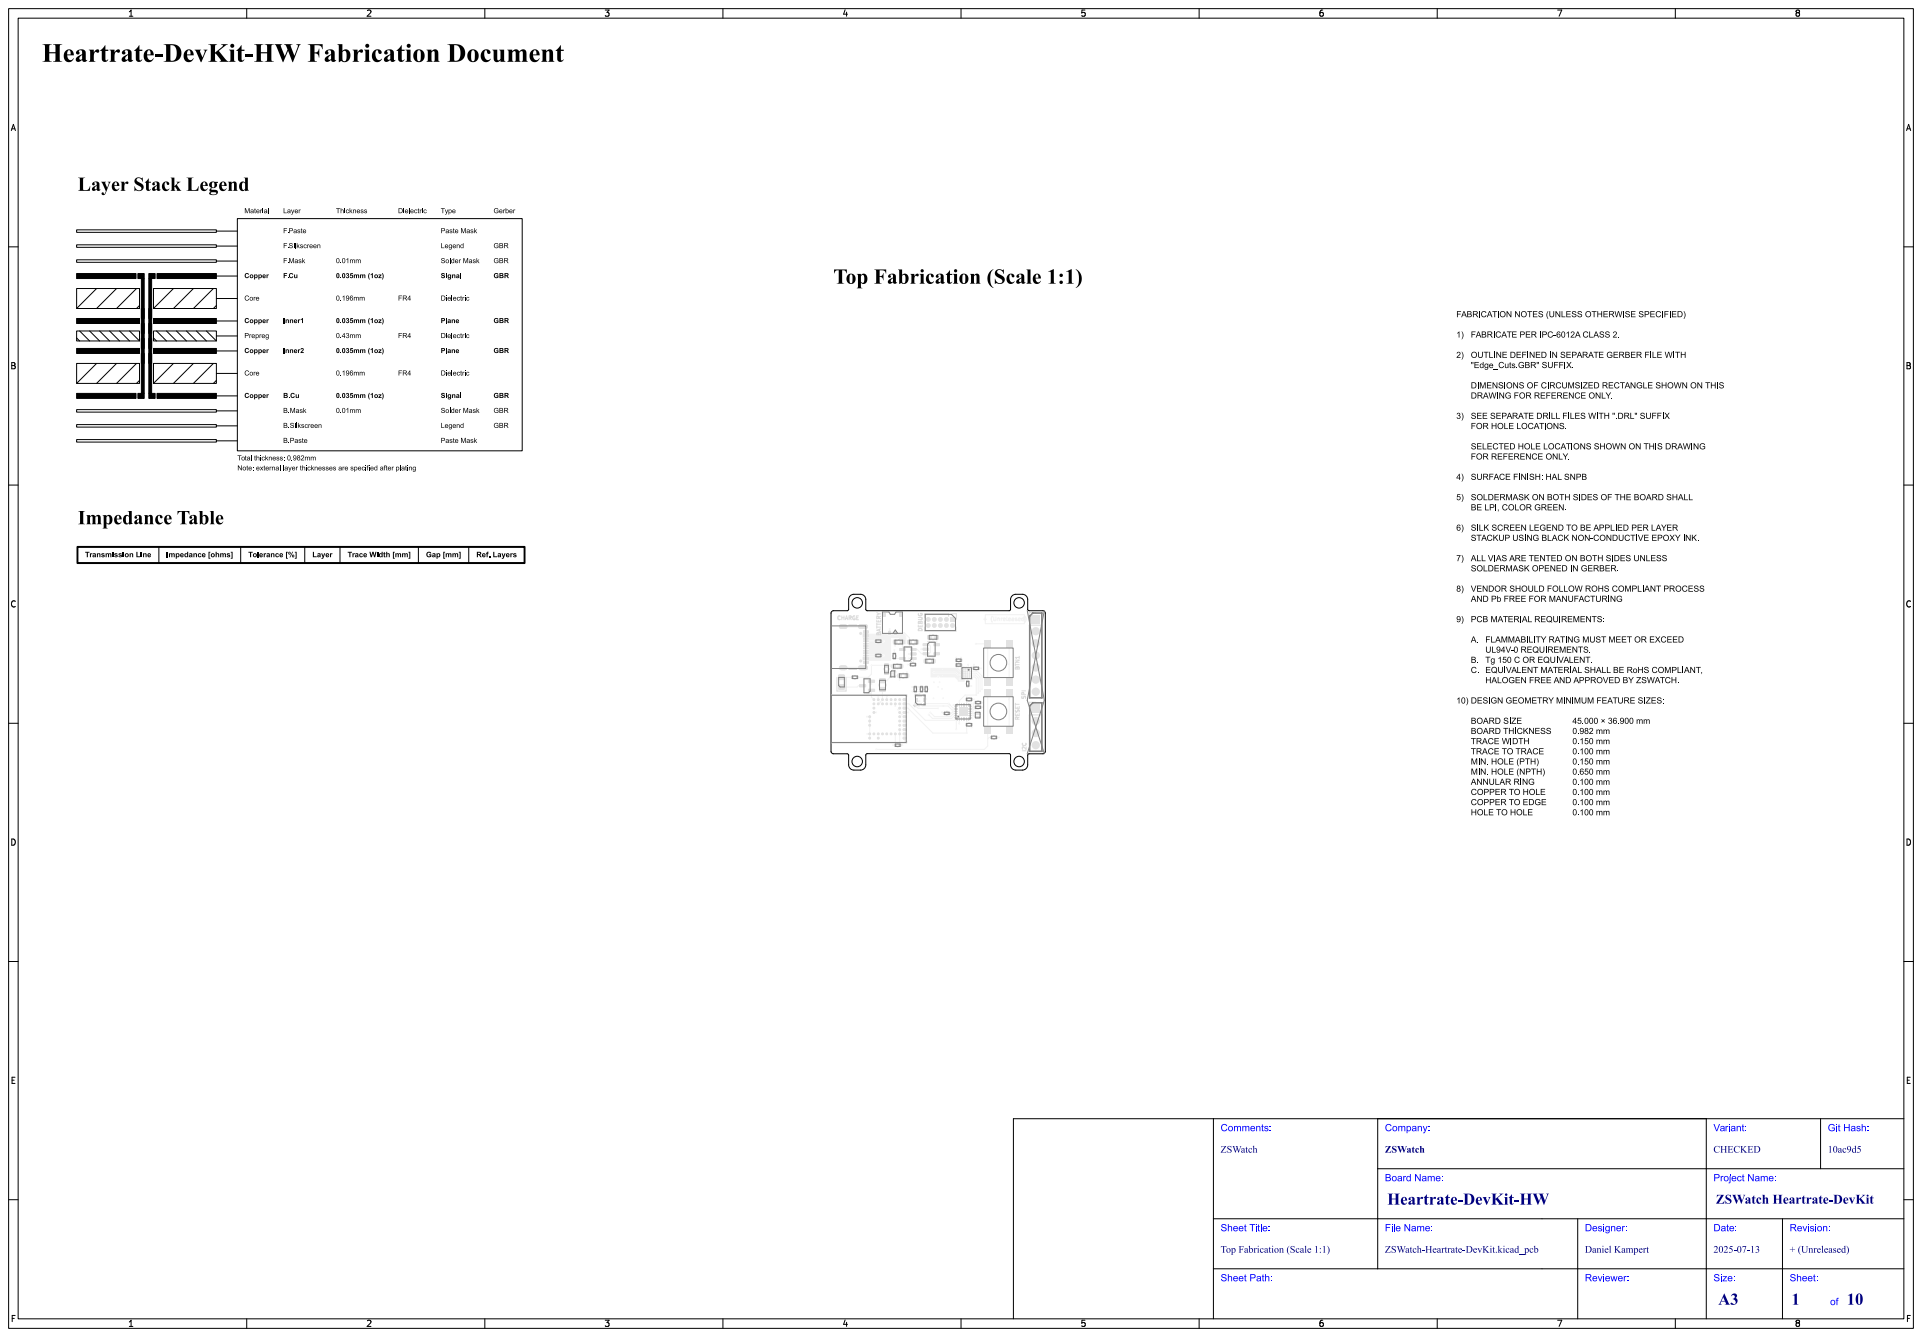
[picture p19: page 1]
Git Hash:; ZSWatch; Comments:; Sheet Path:; Sheet Title:; File Name:; Heartrate-DevKit-HW; ZSWatch Heartrate-DevKit; Company:; CHECKED; Variant:; Board Name:; Designer:; Reviewer:; Project Name:; Date:; + (Unreleased); Revision:; Size:; Sheet:; 8 BATTERY; BTN1 RESET DEBUG; I2C SPI; CHARGE

Top Fabrication (Scale 1:1)

ZSWatch-Heartrate-DevKit.kicad_pcb Daniel Kampert

# Bottom Fabrication (Scale 1:1)

Git; Hash:; ZSWatch; Comments:; Sheet Title:; File Name:; Heartrate-DevKit-HW; ZSWatch Heartrate-DevKit; Company:; CHECKED; Variant:; Board Name:; Designer:; Project Name:; Date:; + (Unreleased); Revision:

Bottom Fabrication (Scale 1:1)

ZSWatch-Heartrate-DevKit.kicad_pcb Daniel Kampert

# Drill Drawing L1 - L4 (Scale 1:1)

Git; Hash:; ZSWatch; Comments:; Drill Drawing (L1 - L4); Sheet Title:; File Name:; Heartrate-DevKit-HW; ZSWatch Heartrate-DevKit; Company:; CHECKED; Variant:; Board Name:; Designer:; Project Name:; Date:; + (Unreleased); Revision:

ZSWatch-Heartrate-DevKit.kicad_pcb Daniel Kampert

# Drill Drawing L1 - L4 (Scale 1:1)

Git; Hash:; ZSWatch; Comments:; Drill Drawing (L1 - L4); Sheet Title:; File Name:; Heartrate-DevKit-HW; ZSWatch Heartrate-DevKit; Company:; CHECKED; Variant:; Board Name:; Designer:; Project Name:; Date:; + (Unreleased); Revision:

ZSWatch-Heartrate-DevKit.kicad_pcb Daniel Kampert

# Top Test Points (Scale 1:1)

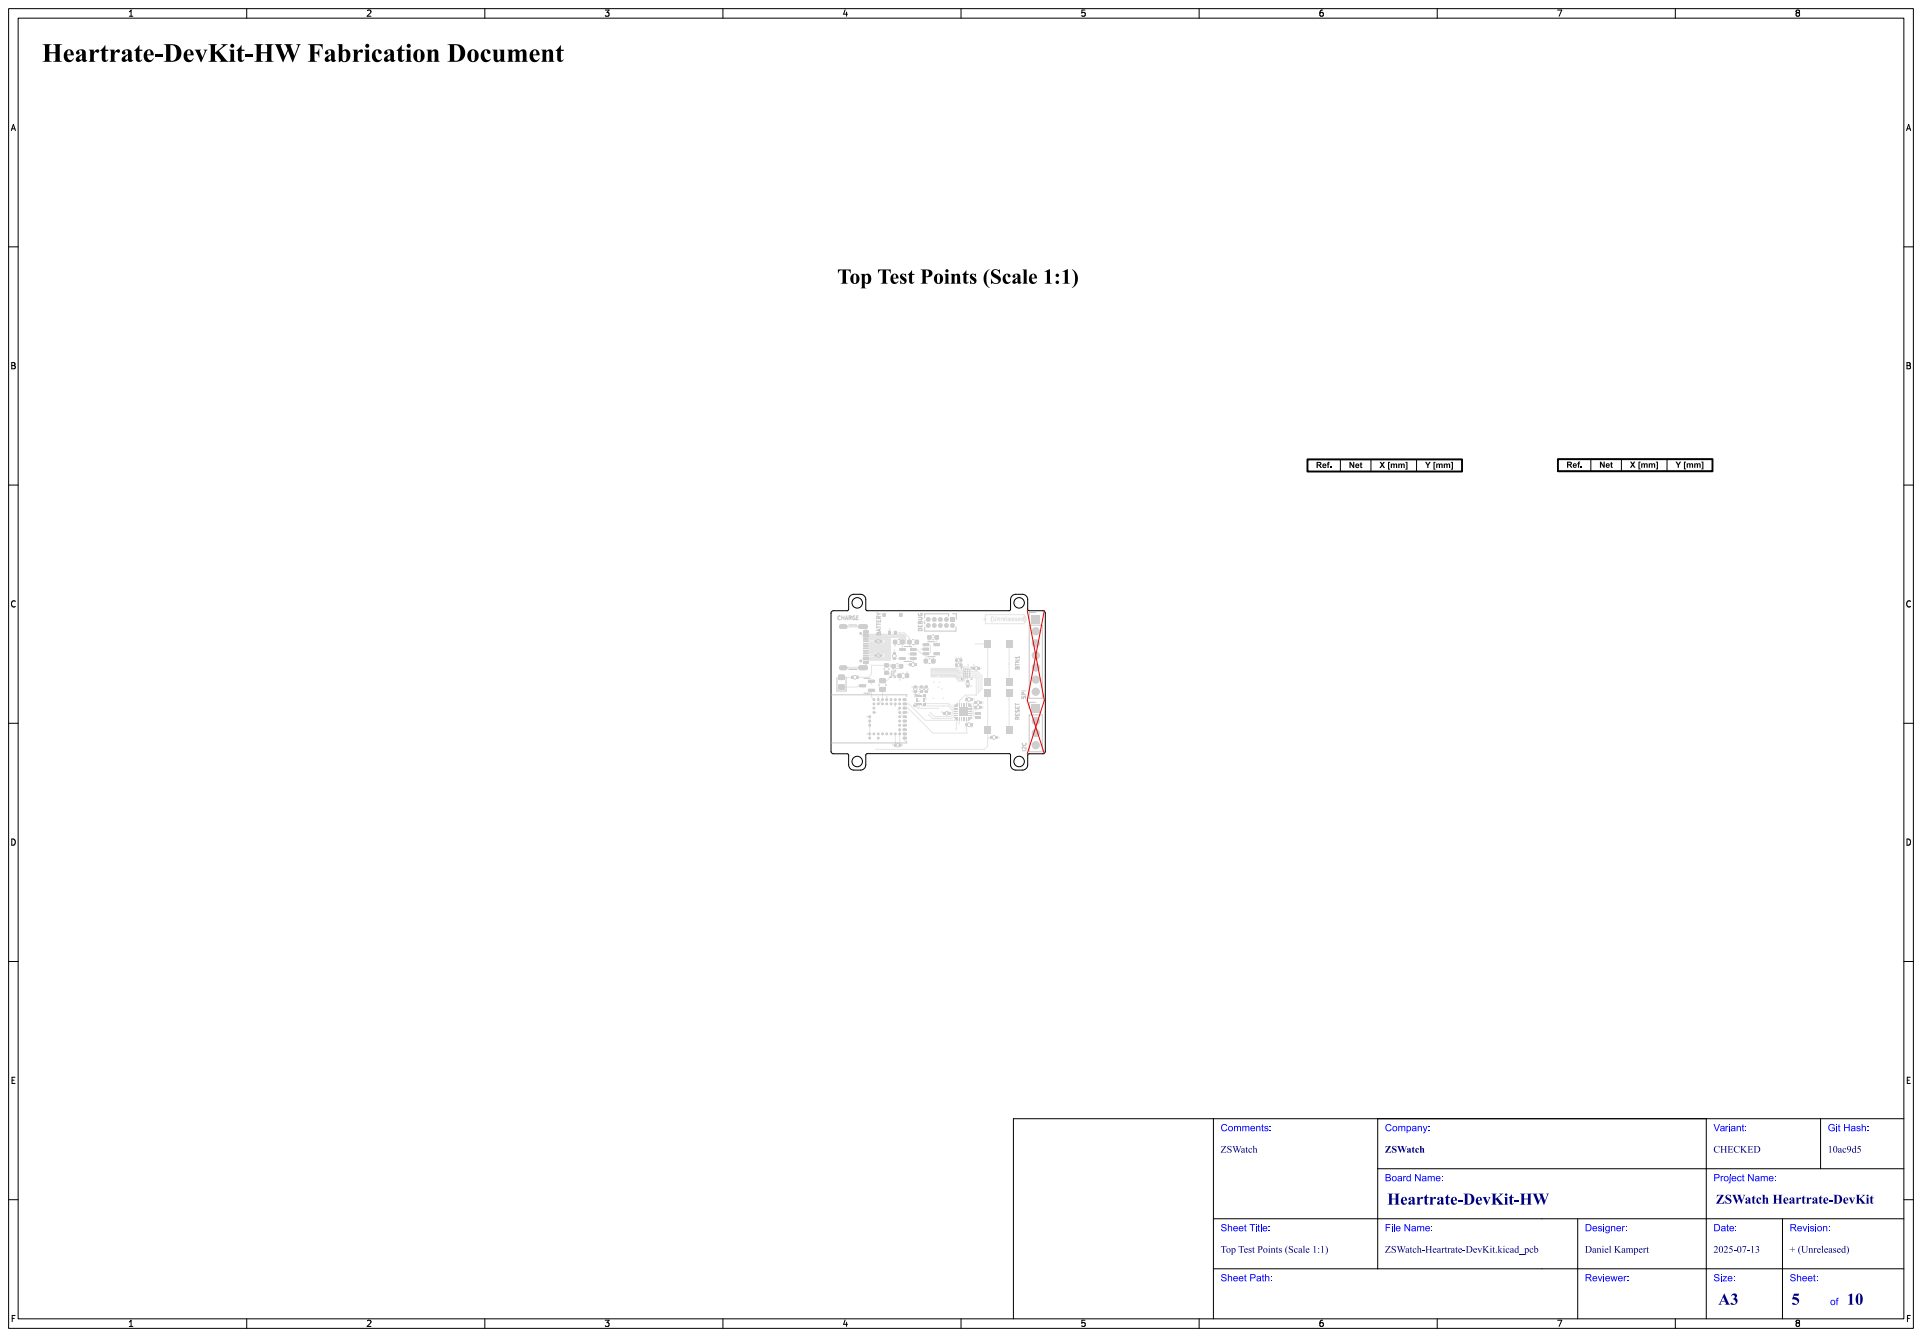
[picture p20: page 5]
Git; Hash:; ZSWatch; Comments:; Sheet Title:; File Name:; Heartrate-DevKit-HW; ZSWatch Heartrate-DevKit; Company:; CHECKED; Variant:; Board Name:; Designer:; Project Name:; Date:; + (Unreleased); Revision:; 8 BATTERY; BTN1 RESET DEBUG; I2C SPI; CHARGE

Top Test Points (Scale 1:1)

ZSWatch-Heartrate-DevKit.kicad_pcb Daniel Kampert

# Bottom Test Points (Scale 1:1)

Git; Hash:; ZSWatch; Comments:; Sheet Title:; File Name:; Heartrate-DevKit-HW; ZSWatch Heartrate-DevKit; Company:; CHECKED; Variant:; Board Name:; Designer:; Project Name:; Date:; + (Unreleased); Revision:

Bottom Test Points (Scale 1:1)

ZSWatch-Heartrate-DevKit.kicad_pcb Daniel Kampert

# F.Cu (Scale 1:1)

Git; Hash:; ZSWatch; Comments:; F.Cu (Scale 1:1); Sheet Title:; File Name:; Heartrate-DevKit-HW; ZSWatch Heartrate-DevKit; Company:; CHECKED; Variant:; Board Name:; Designer:; Project Name:; Date:; + (Unreleased); Revision:

ZSWatch-Heartrate-DevKit.kicad_pcb Daniel Kampert

# Inner1 (Scale 1:1)

Git; Hash:; ZSWatch; Comments:; Inner1 (Scale 1:1); Sheet Title:; File Name:; Heartrate-DevKit-HW; ZSWatch Heartrate-DevKit; Company:; CHECKED; Variant:; Board Name:; Designer:; Project Name:; Date:; + (Unreleased); Revision:

ZSWatch-Heartrate-DevKit.kicad_pcb Daniel Kampert

# Inner2 (Scale 1:1)

Git; Hash:; ZSWatch; Comments:; Inner2 (Scale 1:1); Sheet Title:; File Name:; Heartrate-DevKit-HW; ZSWatch Heartrate-DevKit; Company:; CHECKED; Variant:; Board Name:; Designer:; Project Name:; Date:; + (Unreleased); Revision:

ZSWatch-Heartrate-DevKit.kicad_pcb Daniel Kampert

# B.Cu (Scale 1:1)

Git; Hash:; ZSWatch; Comments:; B.Cu (Scale 1:1); Sheet Title:; File Name:; Heartrate-DevKit-HW; ZSWatch Heartrate-DevKit; Company:; CHECKED; Variant:; Board Name:; Designer:; Project Name:; Date:; + (Unreleased); Revision:

ZSWatch-Heartrate-DevKit.kicad_pcb Daniel Kampert

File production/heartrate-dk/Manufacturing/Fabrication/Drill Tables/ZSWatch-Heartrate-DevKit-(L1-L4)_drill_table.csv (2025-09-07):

Count | Hole Size | Plated | Hole Shape | Drill Layer Pair | Hole Type
88 | 0.15mm (5.91mils) | PTH | Round | F.Cu - B.Cu | Via
4 | 0.60mm (23.62mils) | PTH | Slot | F.Cu - B.Cu | Pad
10 | 0.65mm (25.59mils) | PTH | Round | F.Cu - B.Cu | Pad
11 | 1.00mm (39.37mils) | PTH | Round | F.Cu - B.Cu | Pad
Total 113

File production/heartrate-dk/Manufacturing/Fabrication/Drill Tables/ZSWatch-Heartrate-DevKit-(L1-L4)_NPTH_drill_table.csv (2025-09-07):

Count | Hole Size | Plated | Hole Shape | Drill Layer Pair | Hole Type
2 | 0.65mm (25.59mils) | NPTH | Round | F.Cu - B.Cu | Mechanical
Total 2

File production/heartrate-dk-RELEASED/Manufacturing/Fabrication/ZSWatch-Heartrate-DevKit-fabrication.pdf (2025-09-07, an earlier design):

# Top Fabrication (Scale 1:1)

# Heartrate-DevKit-HW Fabrication Document

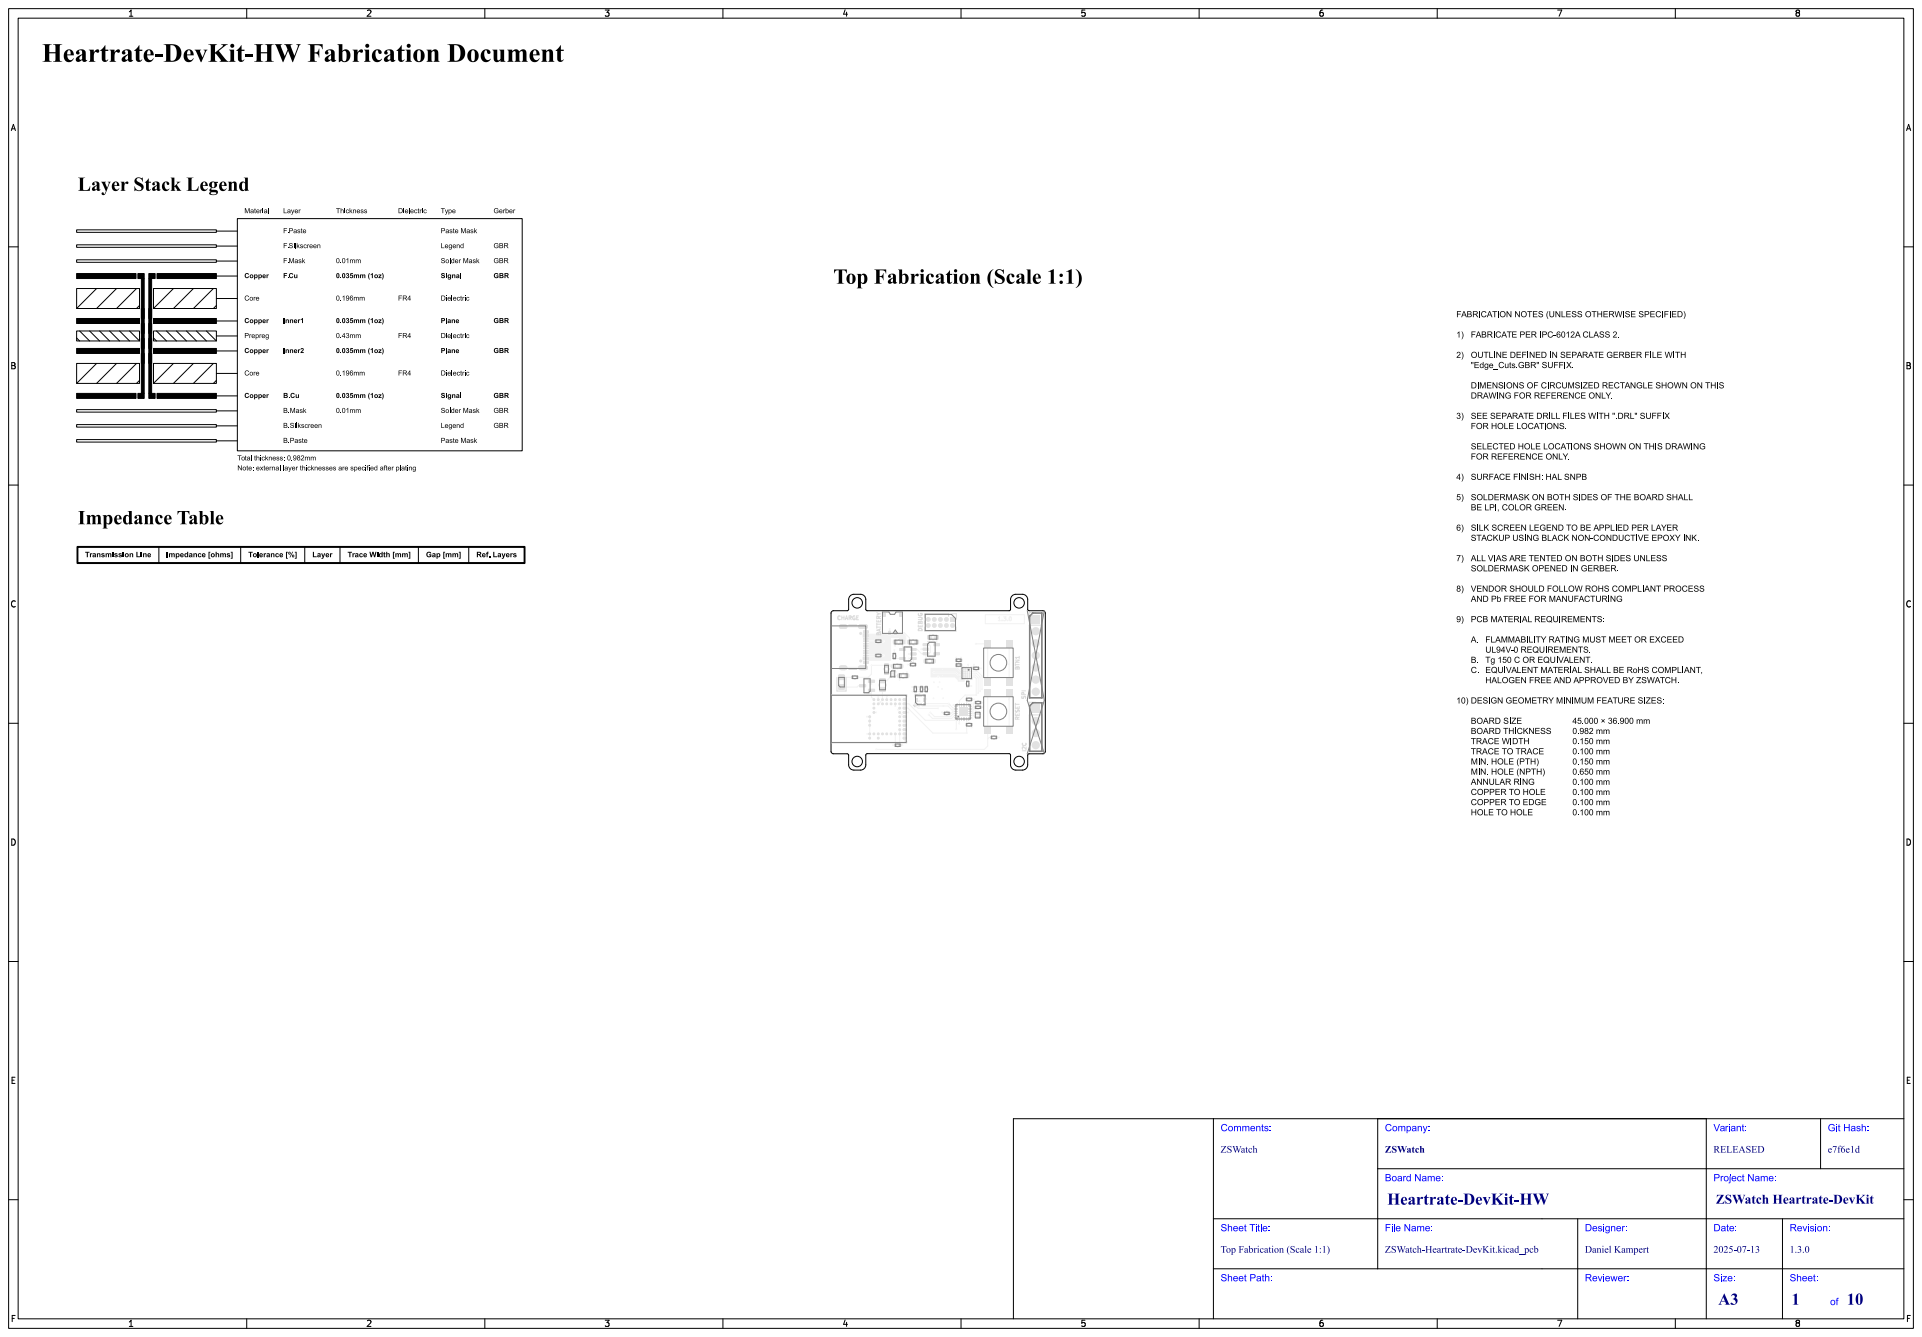
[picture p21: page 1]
Git Hash:; ZSWatch; Comments:; Sheet Path:; Sheet Title:; File Name:; Heartrate-DevKit-HW; ZSWatch Heartrate-DevKit; Company:; RELEASED; Variant:; Board Name:; Designer:; Reviewer:; Project Name:; Date:; Revision:; Size:; Sheet:; 8 BATTERY; BTN1 RESET DEBUG; I2C SPI; CHARGE

Top Fabrication (Scale 1:1)

ZSWatch-Heartrate-DevKit.kicad_pcb Daniel Kampert

# Bottom Fabrication (Scale 1:1)

Git; Hash:; ZSWatch; Comments:; Sheet Title:; File Name:; Heartrate-DevKit-HW; ZSWatch Heartrate-DevKit; Company:; RELEASED; Variant:; Board Name:; Designer:; Project Name:; Date:; Revision:

Bottom Fabrication (Scale 1:1)

ZSWatch-Heartrate-DevKit.kicad_pcb Daniel Kampert

# Drill Drawing L1 - L4 (Scale 1:1)

Git; Hash:; ZSWatch; Comments:; Drill Drawing (L1 - L4); Sheet Title:; File Name:; Heartrate-DevKit-HW; ZSWatch Heartrate-DevKit; Company:; RELEASED; Variant:; Board Name:; Designer:; Project Name:; Date:; Revision:

ZSWatch-Heartrate-DevKit.kicad_pcb Daniel Kampert

# Drill Drawing L1 - L4 (Scale 1:1)

Git; Hash:; ZSWatch; Comments:; Drill Drawing (L1 - L4); Sheet Title:; File Name:; Heartrate-DevKit-HW; ZSWatch Heartrate-DevKit; Company:; RELEASED; Variant:; Board Name:; Designer:; Project Name:; Date:; Revision:

ZSWatch-Heartrate-DevKit.kicad_pcb Daniel Kampert

# Top Test Points (Scale 1:1)

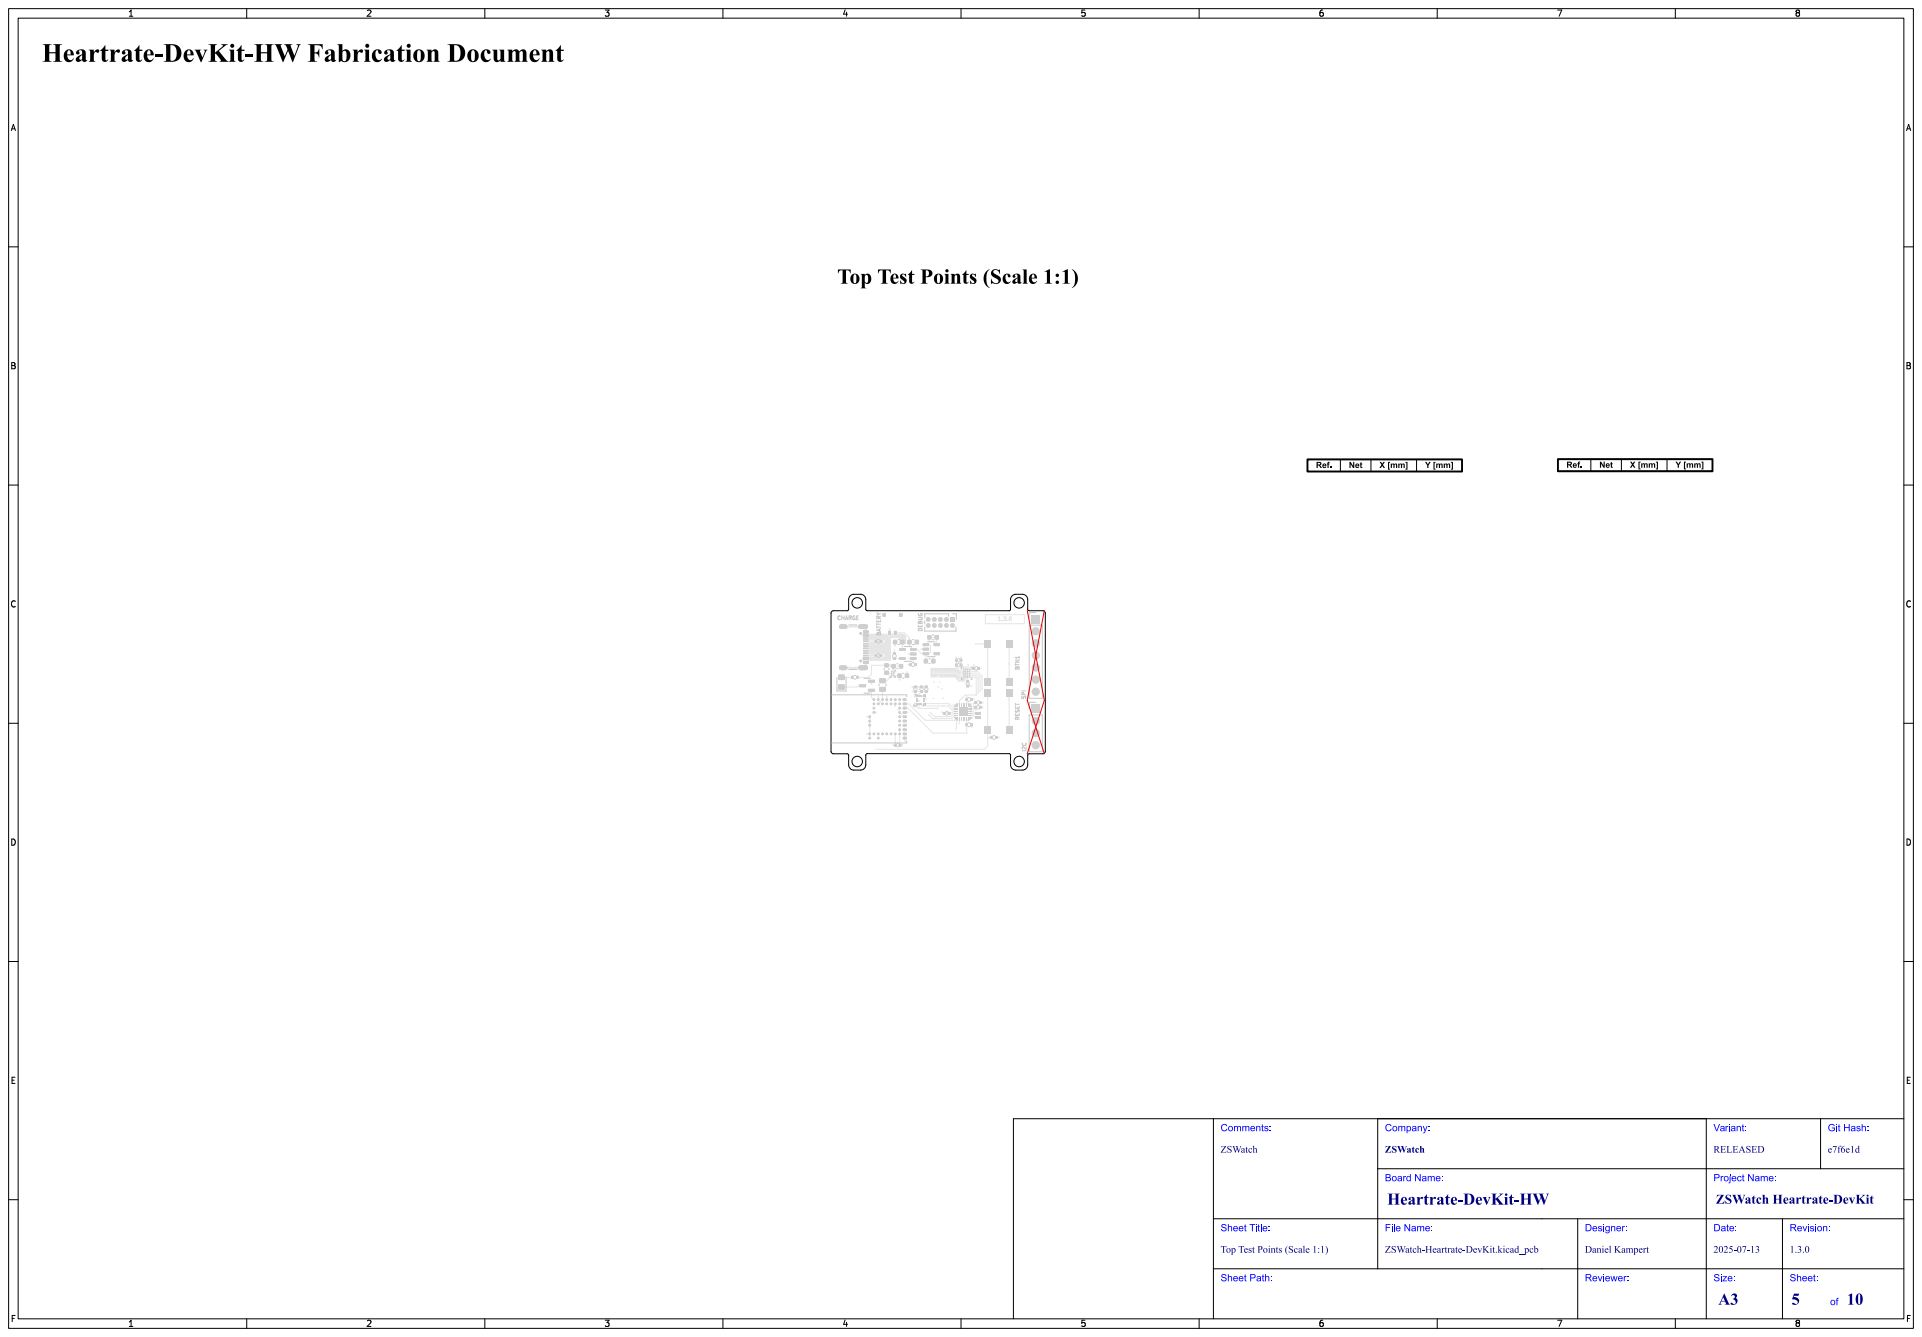
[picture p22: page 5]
Git; Hash:; ZSWatch; Comments:; Sheet Title:; File Name:; Heartrate-DevKit-HW; ZSWatch Heartrate-DevKit; Company:; RELEASED; Variant:; Board Name:; Designer:; Project Name:; Date:; Revision:; 8 BATTERY; BTN1 RESET DEBUG; I2C SPI; CHARGE

Top Test Points (Scale 1:1)

ZSWatch-Heartrate-DevKit.kicad_pcb Daniel Kampert

# Bottom Test Points (Scale 1:1)

Git; Hash:; ZSWatch; Comments:; Sheet Title:; File Name:; Heartrate-DevKit-HW; ZSWatch Heartrate-DevKit; Company:; RELEASED; Variant:; Board Name:; Designer:; Project Name:; Date:; Revision:

Bottom Test Points (Scale 1:1)

ZSWatch-Heartrate-DevKit.kicad_pcb Daniel Kampert

# F.Cu (Scale 1:1)

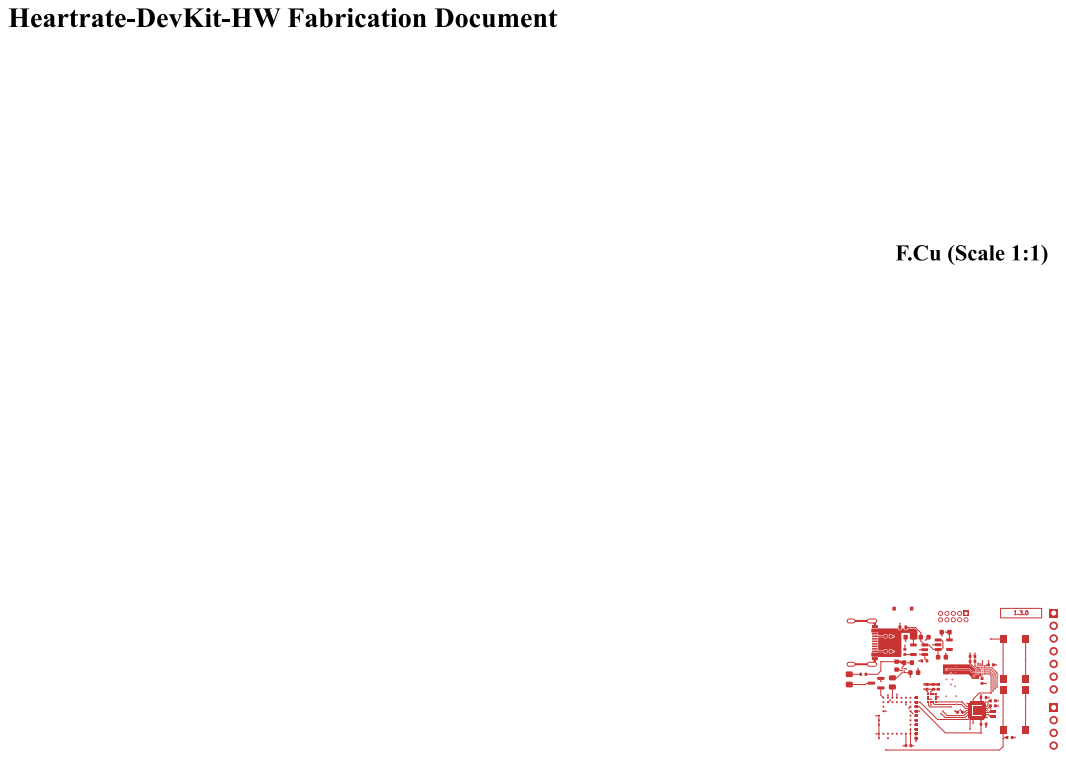
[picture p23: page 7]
Git; Hash:; ZSWatch; Comments:; F.Cu (Scale 1:1); Sheet Title:; File Name:; Heartrate-DevKit-HW; ZSWatch Heartrate-DevKit; Company:; RELEASED; Variant:; Board Name:; Designer:; Project Name:; Date:; Revision:

ZSWatch-Heartrate-DevKit.kicad_pcb Daniel Kampert

# Inner1 (Scale 1:1)

Git; Hash:; ZSWatch; Comments:; Inner1 (Scale 1:1); Sheet Title:; File Name:; Heartrate-DevKit-HW; ZSWatch Heartrate-DevKit; Company:; RELEASED; Variant:; Board Name:; Designer:; Project Name:; Date:; Revision:

ZSWatch-Heartrate-DevKit.kicad_pcb Daniel Kampert

# Inner2 (Scale 1:1)

Git; Hash:; ZSWatch; Comments:; Inner2 (Scale 1:1); Sheet Title:; File Name:; Heartrate-DevKit-HW; ZSWatch Heartrate-DevKit; Company:; RELEASED; Variant:; Board Name:; Designer:; Project Name:; Date:; Revision:

ZSWatch-Heartrate-DevKit.kicad_pcb Daniel Kampert

# B.Cu (Scale 1:1)

Git; Hash:; ZSWatch; Comments:; B.Cu (Scale 1:1); Sheet Title:; File Name:; Heartrate-DevKit-HW; ZSWatch Heartrate-DevKit; Company:; RELEASED; Variant:; Board Name:; Designer:; Project Name:; Date:; Revision:

ZSWatch-Heartrate-DevKit.kicad_pcb Daniel Kampert

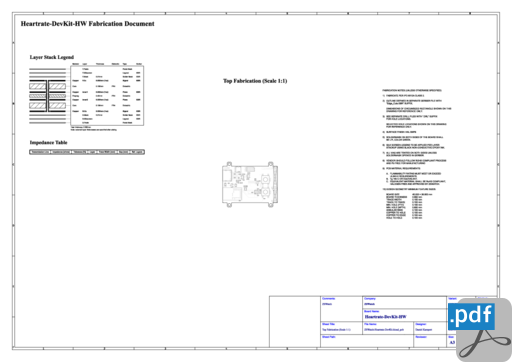
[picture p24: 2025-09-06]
production/heartrate-dk/HTML/images/cat_pdf_fabrication_ZSWatch-Heartrate-DevKit-fabrication.png

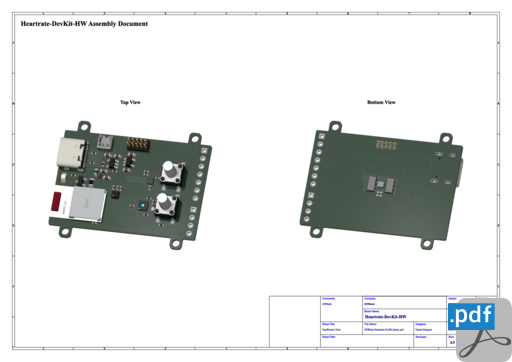
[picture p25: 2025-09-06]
production/heartrate-dk/HTML/images/cat_pdf_assembly_ZSWatch-Heartrate-DevKit-assembly.png

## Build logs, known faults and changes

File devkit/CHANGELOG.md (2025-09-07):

# Changelog

## [Unreleased]

## [1.3.0] - 2025-09-07

### Fixed

-   Fix wrong status LED (#2)
-   Fix wrong I2C pins (#5)

### Added

-   Add MFIO signal to SPI header (#16)
-   New KiBot template
-   Add second photo diode (#4)

### Changed

-   Replace VEMD8080 with VEMD8082 (#8)
-   Replace single LEDs with tripple color LED (#7)
-   Move SWD connector away from battery connector (#14)

[Unreleased]: https://github.com/ZSWatch/Heartrate-DevKit-HW/compare/1.3.0...HEAD

[1.3.0]: https://github.com/ZSWatch/Heartrate-DevKit-HW/compare/b0609d8e1e96f104fe69c6613989c0a8bdc5bf99...1.3.0

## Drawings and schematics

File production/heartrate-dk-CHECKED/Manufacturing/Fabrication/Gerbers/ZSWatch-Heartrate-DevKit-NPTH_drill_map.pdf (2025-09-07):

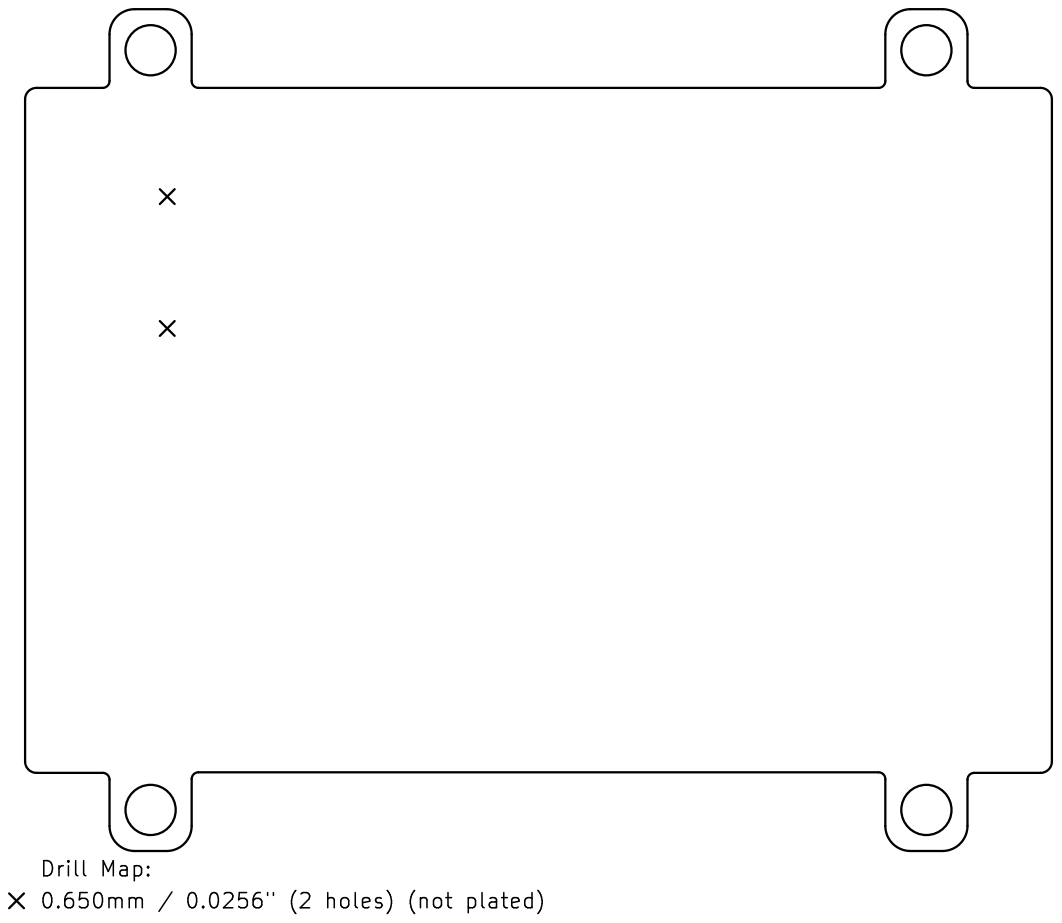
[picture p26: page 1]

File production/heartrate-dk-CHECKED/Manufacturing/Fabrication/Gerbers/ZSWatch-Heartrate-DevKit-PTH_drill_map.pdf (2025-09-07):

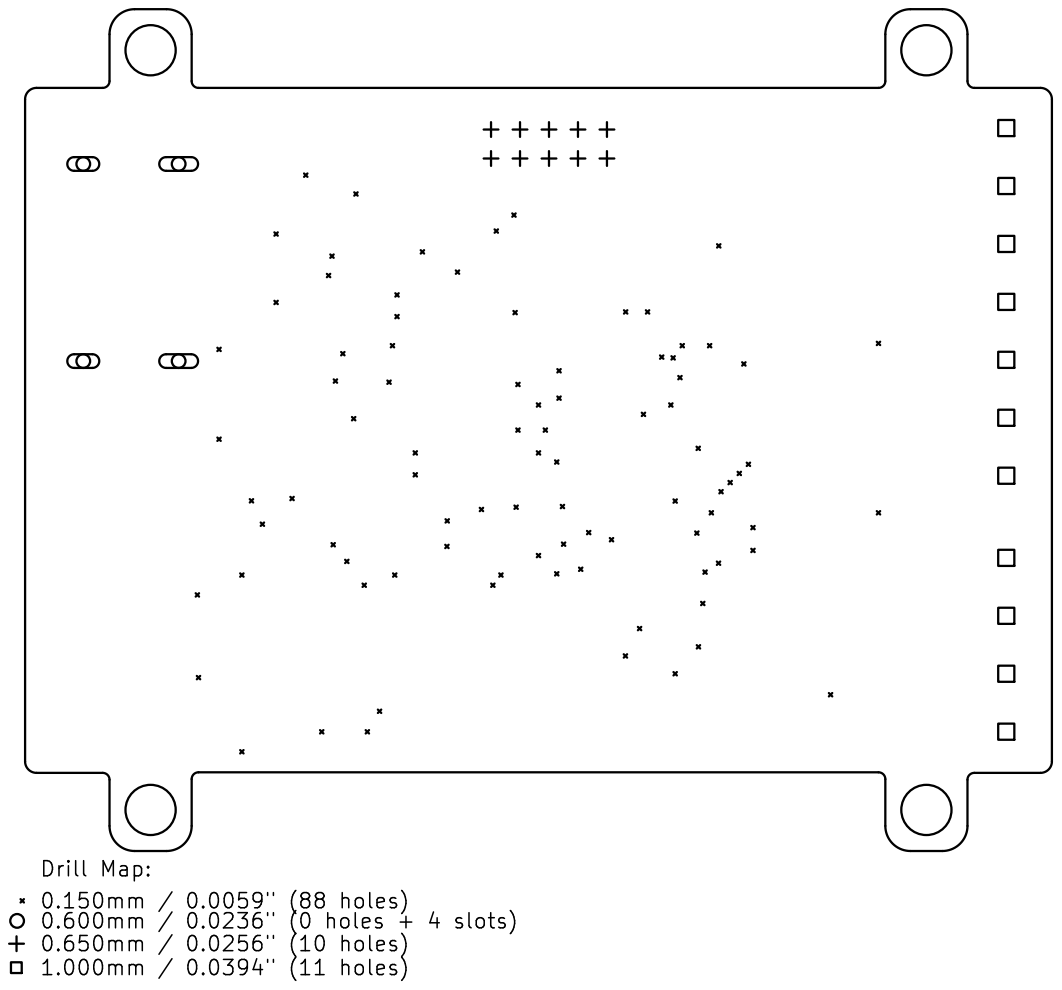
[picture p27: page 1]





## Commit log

2025-09-06 Push outputs from CI/CD (2025-09-06 09:53:54)
    [ZSWatch-Heartrate-DevKit-(L1-L4)_NPTH_drill_table.csv, ZSWatch-Heartrate-DevKit-(L1-L4)_drill_table.csv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]
2025-09-07 Prepare release
    - Set variant to CHECKED
    - Remove unused files
    - Fix ERC errors
    - Fix DRC errors
    - Fix different documentation errors
    - Fix different path errors for the release build
    - Remove Power Sequencing page
    - Add PDF_REPORT_ROOT_DIR variable to build
    - Add script for CHANGELOG generation
    [Main.kicad_sch, Power - Sequencing.kicad_sch, Revision History.kicad_sch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]
2025-09-07 Update outputs (release)
    [ZSWatch-Heartrate-DevKit-(L1-L4)_NPTH_drill_table.csv, ZSWatch-Heartrate-DevKit-(L1-L4)_drill_table.csv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]
2025-09-07 Push outputs from CI/CD (2025-09-07 20:00:07)
    [ZSWatch-Heartrate-DevKit-(L1-L4)_NPTH_drill_table.csv, ZSWatch-Heartrate-DevKit-(L1-L4)_drill_table.csv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]
